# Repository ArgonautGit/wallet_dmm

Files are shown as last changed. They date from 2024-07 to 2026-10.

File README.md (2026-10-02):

# wallet_dmm

A multimeter the size of a credit card: DC volts, resistance, continuity and
diode test, shown on a 0.91" OLED, with three buttons, an RGB LED and a piezo
beeper. It runs from a small LiPo that charges over USB-C and is built around
an STM32L051K8, with Rust firmware and a simulation of the whole thing.

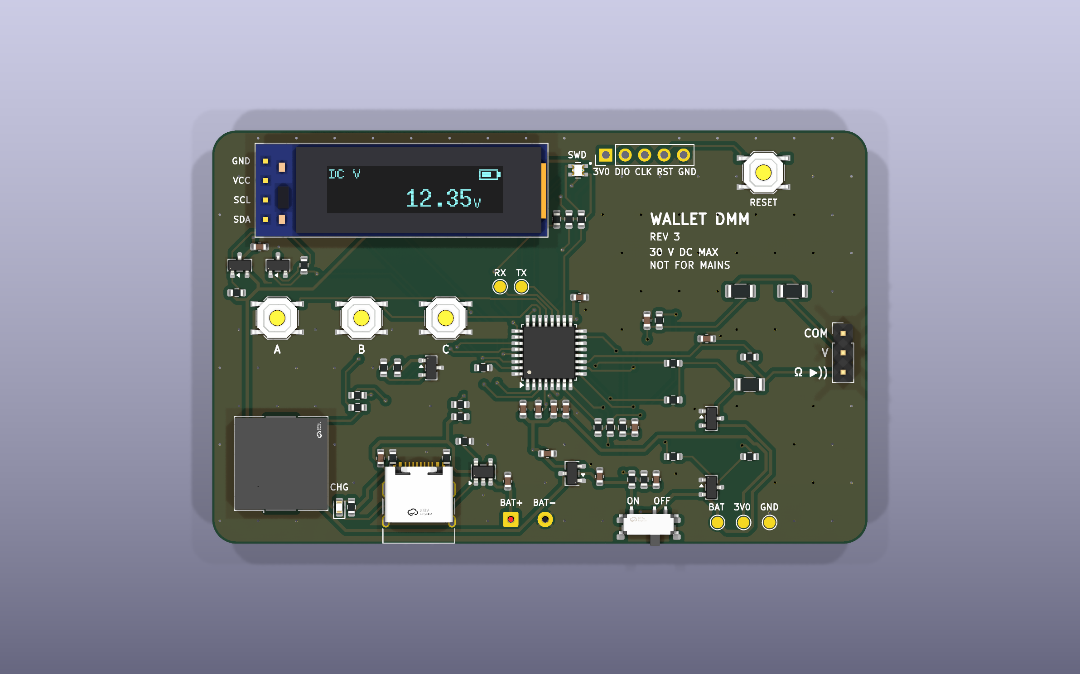
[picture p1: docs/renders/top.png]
The assembled board


This is revision 3. Rev 1 (the October 2024 JLCPCB order) is commit `a01ea68`;
rev 2 is the `v2` branch.

| | |
|---|---|
| Inputs | COM, V (10 MΩ) and Ω (resistance, continuity, diode) on a 2.54 mm header |
| Voltage | −30 V to +31 V; negative readings through a 1.55 V mid-rail bias |
| Resistance | 0–200 kΩ against a 0.1 % 10 kΩ reference, 150 kΩ–10 MΩ against 1 MΩ, autoranging |
| Continuity, diode | 0.3 mA test current, open-circuit 3.0 V |
| Overload | both inputs survive ±30 V DC; not for mains or anything above 30 V |
| Power | 3.7 V LiPo (protected cell), 100 mA USB-C charging, 3.0 V rail, about 5 µA off |
| Board | 85.6 × 54 mm (ID-1 card), 2 layers, 0.8 mm FR4 |

## Changes from rev 1 and rev 2

- **Power.** The CR1025 (rated 0.1 mA continuous) could not run an OLED. It is
  replaced by a LiPo charged from USB-C (MCP73831), a 1 µA 3.0 V LDO that
  stays on while the MCU sleeps in Stop mode, a slide switch that disconnects
  the battery, bulk decoupling, and a load switch (Q1/Q2) that cuts the OLED
  module's supply.
- **Piezo.** The always-running 555 and its two MOSFETs are gone. The MCU
  drives the piezo push-pull from TIM22 CH1/CH2 on PB4/PB5, which gives
  6 Vp-p from 3 V and draws nothing when silent.
- **Programming.** SWD is on PA13/PA14 with NRST, with nothing else on those
  pins. USART1 (PA9/PA10, also the ROM bootloader) is on test pads.
- **Measurement.** Separate V and Ω inputs. The V input is a 9.87 MΩ divider
  biased to a mid-rail reference, with a hold capacitor because the ADC wants
  a source below 50 kΩ. The Ω input has two reference ranges; its drive nodes
  are clamped to ground and the battery, so a voltage on it pushes at most
  2.5 mA into the cell instead of into the MCU or the 3.0 V rail. What the
  MCU pins' own clamps still pass would lift the rail while the MCU sleeps
  (the LDO cannot sink current), so a TL431 (U4) holds it below 3.32 V.
- **Everything else.** A resistor for each LED colour, with the anode on the
  battery so green and blue have headroom. The MCU's calibrated internal
  sensor replaces the TO-92 MCP9700. Decoupling sits at the pins. Every part
  is stocked by JLCPCB and carries its LCSC number. All libraries are in the
  repo.

## Layout of the repository

- `hardware/`: KiCad 10 project (schematic, board, project rules, footprints
  for the RGB LED and the OLED module, 3D models for every part)
- `scripts/`: generators for the schematic, board and 3D models, the
  autorouter wrapper, the fab-file export and the renders
- `fab/`: Gerbers, drill files, BOM and pick-and-place for JLCPCB, schematic
  and assembly PDFs
- `firmware/`: Rust firmware and its simulation (see
  [firmware/README.md](firmware/README.md))
- `docs/`: renders of the board and the simulation results

## Building

Everything runs in the dev shell (`nix develop`, or direnv).

```sh
./scripts/build.sh          # schematic -> ERC -> board -> DRC -> fab/
```

The schematic and board are generated by `scripts/gen_schematic.py` and
`scripts/gen_pcb.py`; edit those rather than the KiCad files, or the next
build will overwrite the change. Tracks come from `hardware/routes.json`.
After moving parts or changing the netlist, route again with Freerouting:

```sh
kicad-cli sch export netlist --format kicadsexpr -o build/wallet_dmm.net hardware/wallet_dmm.kicad_sch
python3 scripts/autoroute.py build/wallet_dmm.net
```

The build stops on any ERC or DRC error and checks that the board matches the
schematic.

The renders in `docs/renders/` and a GLB of the populated board
(`build/wallet_dmm.glb`, for any glTF viewer) come from:

```sh
./scripts/render.sh
```

Most parts use KiCad's own 3D models; the switches, buzzer, USB-C socket and
RGB LED use the manufacturers' models (via EasyEDA). The OLED module and the
battery are drawn by `scripts/gen_models.py`, which lights the OLED's pixels
with the firmware's volts screen:

```sh
nix develop .#models -c uv run --with cadquery python scripts/gen_models.py
```

## Ordering from JLCPCB

Upload `fab/wallet_dmm-gerbers.zip`: 2 layers, **0.8 mm**, 1 oz, any colour,
HASL lead-free or ENIG. For assembly, choose top side and upload
`fab/bom-jlcpcb.csv` and `fab/cpl-jlcpcb.csv`. In the placement preview,
check the orientation of U1 (pin 1 dot), U2, U3, Q1, Q2, D2, D3, D1 (cathode)
and D4 (anode corner, the dot in the silkscreen) before confirming.

Solder these by hand afterwards:

- J3: a 0.91" 128×32 SSD1306 I2C module, flat on the board, header pins cut
  short. Match the module's pin labels to the silkscreen (GND VCC SCL SDA).
- J2: a 3-pin header or the probe leads (COM, V, Ω).
- J5: the battery wires from the back, BAT+ to the square pad.
- J4 stays empty; hold a header in it for an ST-Link, or solder one while
  developing.

## Battery

A LiPo pouch cell with its own protection circuit, up to 30 × 40 × 4 mm,
taped to the marked area on the back (no pins poke through there). Charging
runs at 100 mA, so use 150 mAh or more; R3 sets the current (1000 V / R3).

## Bring-up

1. Before connecting anything, check that BAT and 3V0 (TP3, TP4) are not
   shorted to GND.
2. Connect the battery and slide SW5 to ON. TP4 reads 2.94–3.06 V. If it
   reads 0 V, the switch is the other way round from the silkscreen: fix the
   labels in `scripts/gen_pcb.py`.
3. Plug in USB-C: the CHG LED lights while the cell charges and goes out when
   it is full.
4. Flash over SWD (ST-Link on J4: 3V0, SWDIO, SWCLK, NRST, GND). Holding
   RESET while connecting works if firmware has put the MCU to sleep.
5. With the firmware running ([firmware/README.md](firmware/README.md)):
   short V to COM in DC V and hold C for 3 s to store the zero; do the same
   with the Ω leads in Ω mode. Then put 5–30 V on the V input, measure it with another
   meter, and send `cal <volts>` over the UART (TP2) to set the gain.

## Firmware

The firmware is in [firmware/](firmware/): Rust and Embassy, with all the
maths and the UI in a host-tested crate. Its README covers the buttons,
calibration, flashing and the simulation. The pins:

| Pin | Use |
|---|---|
| PA0 ADC_IN0 | E_LO: the low-range drive node, through R18 |
| PA1 ADC_IN1 | VMID, the bias under the V divider |
| PA2 | VMID_EN: high while measuring volts |
| PA3 | OHM_HI: high-range drive (1 MΩ), analog otherwise |
| PA4 ADC_IN4 | V input divider |
| PA5 ADC_IN5 | Ω input, through R21 into C13 |
| PA6 | OHM_LO: low-range drive (10 kΩ), analog otherwise |
| PA7 | VBUS present (high on USB) |
| PB1 ADC_IN9 | switched battery ÷ 2 |
| PA8, PA15, PB3 | LED blue, red, green (low = on; PA15/PB3 are TIM2 CH1/CH2) |
| PB4, PB5 | piezo, TIM22 CH1/CH2 in antiphase, about 4 kHz |
| PB6, PB7 | I2C1 to the OLED (address 0x3C) |
| PC15 | OLED power: high = on |
| PA11, PA12, PC14 | buttons A, B, C to GND (enable pull-ups) |
| PA9, PA10 | USART1 TX/RX on TP1/TP2 |

## Simulation

`firmware/simulate.sh` runs the front end in ngspice, feeds it through a
model of the ADC into the firmware's own maths, and runs the release binary
in Renode on an emulated STM32L051. Across 200 simulated boards with 1 %
parts, calibrated volts are within ±4 mV up to ±5 V and ±33 mV at ±30 V,
and ohms within ±0.34 % from 1 kΩ to 100 kΩ. The details and plots are in
[firmware/README.md](firmware/README.md#simulation) and
[docs/simulation/](docs/simulation/).

The firmware's display in Renode, step by step

## Renders

| Front | Back, with the battery |
|---|---|
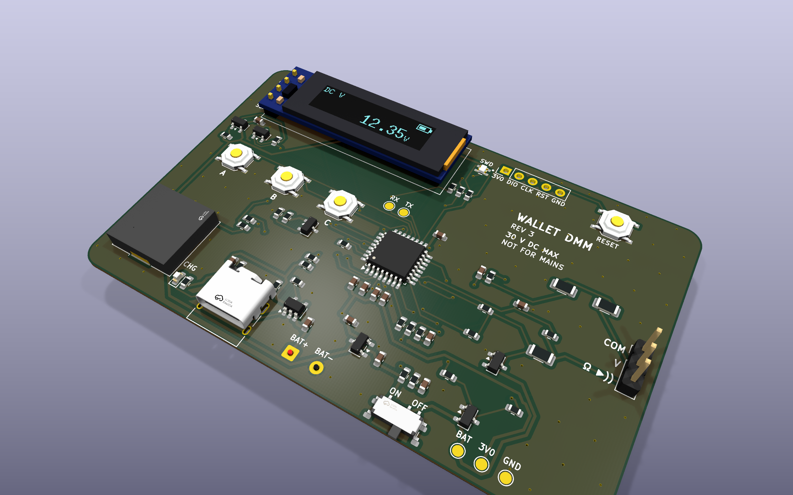
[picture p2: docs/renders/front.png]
Front
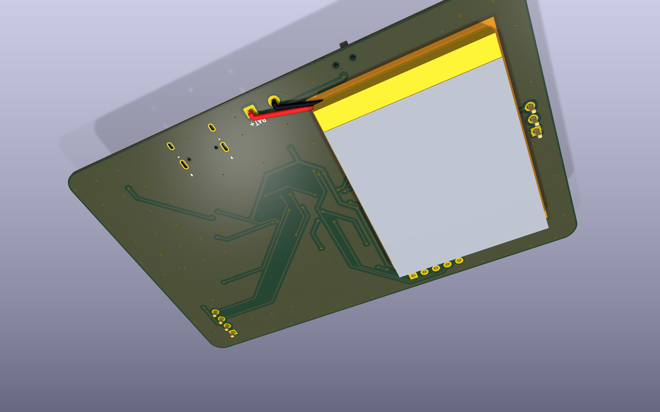
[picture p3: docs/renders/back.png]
Back
|  |  |

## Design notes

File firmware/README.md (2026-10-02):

# Firmware

Rust and Embassy on the STM32L051K8, with a simulation of the analog front
end, the ADC and the firmware itself.

- `core/`: everything that is not a pin. The measurement maths (divider,
  references, VDDA from VREFINT, battery, temperature), the UI state machine
  and the 128×32 screen layout. `no_std`, tested on the host.
- `app/`: the firmware binary. Pins, ADC registers, EEPROM, Stop mode.
- `sim/`: the front end in ngspice, an ADC model that feeds `core`, and plots.
- `renode/`: the release ELF running on an emulated STM32L051 with a model
  of the front end behind its ADC.

## Using the meter

| Button | Short press | Long press |
|---|---|---|
| A | next mode: DC V, Ω, continuity, diode, info | 1.5 s: off |
| B | hold the display (again to release) | |
| C | relative: show readings against the current one | 3 s, probes shorted: store the zero |

Any button wakes the meter from off. It turns itself off after 5 minutes
without a press, or when the battery falls below 3.35 V, unless USB is
connected; the blue LED blinks while it is.

- **DC V**, on the V input: −30 V to +31 V, "OL" beyond. Readings are
  averaged while the input holds still and start over when it moves.
- **Ω**, on the Ω input: the 10 kΩ range up to 200 kΩ, the 1 MΩ range above
  (back below 150 kΩ), "OL" when open. Before each reading the drive is
  pulled low to look for a source on the input; "VOLTS!" and the red LED
  mean there is one, and nothing is driven until it goes.
- **Continuity**: beeps, with the green LED, below 50 Ω. Reads every 30 ms.
- **Diode**: forward voltage at up to 0.3 mA, "OL" when open or reversed.
- **Info**: battery voltage and charge, USB, the MCU's temperature, VDDA.

## Calibration

Stored in the data EEPROM, so it survives power-off and reflashing.

- **Zero** (volts offset, lead resistance): short the probes in DC V, Ω or
  continuity and hold C for 3 s.
- **Gain**: put a steady 5–30 V on the V input, measure it with a meter you
  trust, and send `cal <volts>` (for example `cal 10.047`) to USART1 RX on
  TP2. The firmware replies with the new gain, or with why it refused (not
  in DC V, below 1 V, or more than 5 % off).

## Log

USART1 TX on TP1, 115200 8N1. One line per reading, with µV, mΩ, the rail
(µV), the battery (µV) and the temperature (0.1 °C):

```
DC V 12335998 vdda 2968467 bat 3899510 temp 241
OHMS 470046813 vdda 2968467 bat 3899782 temp 241
button A long
off
```

## Building and flashing

In the firmware dev shell (`nix develop .#firmware` at the repository root):

```sh
cargo test -p dmm-core     # host tests, in firmware/
cd app
cargo build --release      # 35 KB of the 64 KB flash
cargo run --release        # flash over SWD (ST-Link on J4) with probe-rs
```

The app builds for `thumbv6m-none-eabi` through `app/.cargo/config.toml`,
so run cargo from `app/`. If the meter is off (Stop mode), probe-rs cannot
attach: hold RESET while it connects, or add `--connect-under-reset` to the
runner in that file.

## Simulation

```sh
./simulate.sh    # in firmware/; refreshes docs/simulation/
```

It runs four layers:

1. `cargo test`: the maths and UI.
2. `sim/spice.py`: the front end in ngspice. DC sweeps of both inputs,
   30 V on each input with the MCU running and asleep, the continuity and V
   settling transients, and 200 boards with 1 % resistors (0.1 % for R17).
3. `dmm-sim`: turns those node voltages into ADC codes with offset, gain
   error, INL, noise, 16× oversampling and each board's own ADC errors, then
   into readings through `core`, exactly as the firmware does. It also draws
   each screen with the firmware's renderer.
4. `renode/run.py`: the release ELF on an emulated STM32L051. A Python
   peripheral stands in for the ADC and solves the front end from the GPIO
   state the firmware sets up. A scripted session presses buttons, changes
   what the probes touch, and types a calibration command. The SSD1306's I2C
   traffic is decoded back into frames.

Results, in [docs/simulation](../docs/simulation/):

| Check | Result |
|---|---|
| Volts, uncalibrated | ±61 mV up to ±5 V, ±505 mV at ±30 V |
| Volts, zero and gain calibrated | ±4 mV up to ±5 V, ±33 mV at ±30 V |
| Ohms, leads zeroed, up to 100 Ω | ±3.1 Ω |
| Ohms, 1 kΩ–100 kΩ | ±0.34 % |
| Ohms, 1 MΩ / 10 MΩ | ±1.5 % / ±3.6 % |
| Diode test, 1N4148 / red LED | 0.516 V / 1.704 V (true 0.516 / 1.705) |
| 30 V on the Ω input | 2.5 mA into the battery, 65 mW in R17 |
| Same, MCU asleep | rail held at 3.32 V by U4 (29.5 V without it) |
| Continuity | beeps at the first reading after contact, 15 ms |
| V input settling | 161 ms to 5 mV; readings every 200 ms |

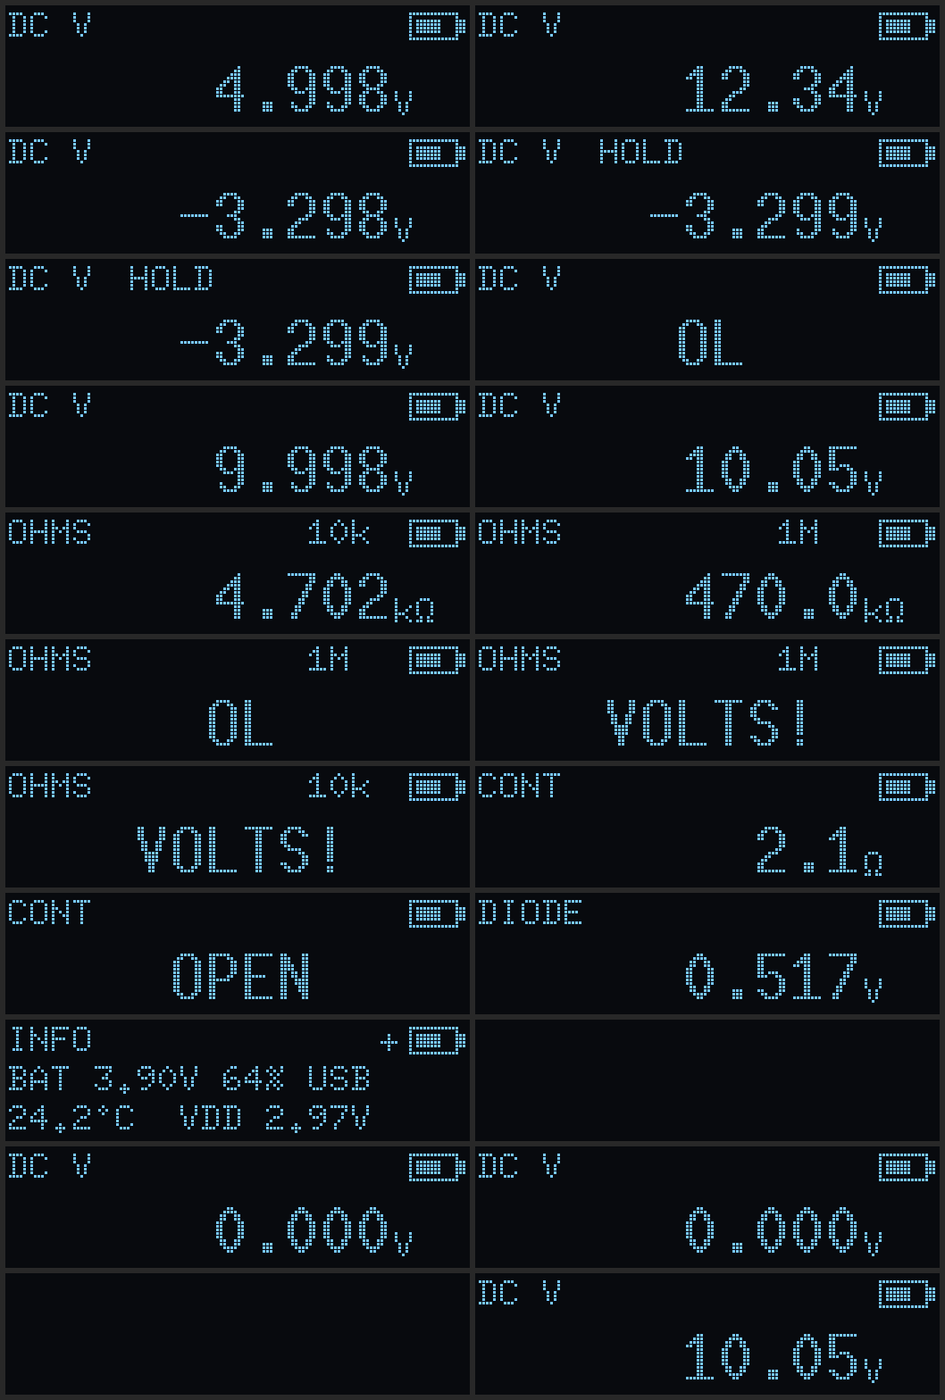
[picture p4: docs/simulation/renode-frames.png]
Readings from the firmware running in Renode


The Renode session (`session.md` there) checks the log line, LEDs, piezo and
OLED power at the end of each step, including hold, overload on both inputs,
autoranging, power-off and wake, and the zero and gain surviving a reset.

Renode 1.16 differs from the real chip in ways that `run.py` works around:
a system reset clears flash and pulls every GPIO input low (the reset macro
reloads the ELF and lets the buttons go), EXTI_IMR resets to 0 instead of
0x3F840000 (which would mask USART1's interrupt), and PC14 does not reach
the EXTI (button C drives the EXTI line directly).

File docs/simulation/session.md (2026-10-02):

| Step | Last UART line | LEDs lit | Piezo | OLED power |
|---|---|---|---|---|
| volts_5V | DC V 5001079 vdda 2968248 bat 3899948 temp 242 | - | off | on |
| volts_12V34 | DC V 12335998 vdda 2968467 bat 3899510 temp 241 | - | off | on |
| volts_neg3V3 | DC V -3296296 vdda 2968577 bat 3899564 temp 241 | - | off | on |
| volts_hold | DC V -3302042 vdda 2967918 bat 3899242 temp 242 | - | off | on |
| volts_hold_kept | DC V 19992218 vdda 2967918 bat 3899422 temp 243 | - | off | on |
| volts_overload | DC V overload vdda 2968357 bat 3899728 temp 242 | - | off | on |
| volts_10V | DC V 9998416 vdda 2968357 bat 3899638 temp 242 | - | off | on |
| volts_cal_10V05 | DC V 10048082 vdda 2967698 bat 3898952 temp 241 | - | off | on |
| ohms_4k7 | OHMS 4702061 vdda 2968138 bat 3899350 temp 242 | - | off | on |
| ohms_470k | OHMS 470046813 vdda 2968467 bat 3899782 temp 241 | - | off | on |
| ohms_open | OHMS open vdda 2968138 bat 3899168 temp 242 | - | off | on |
| ohms_voltage | OHMS overload vdda 2968357 bat 3899456 temp 242 | red | off | on |
| ohms_negative_voltage | OHMS overload vdda 2968357 bat 3899274 temp 243 | red | off | on |
| continuity_short | CONT 2357 vdda 2968138 bat 3899258 temp 243 | green | on | on |
| continuity_open | CONT open vdda 2968138 bat 3899622 temp 242 | - | off | on |
| diode_1n4148 | DIODE 517094 vdda 2968028 bat 3899568 temp 242 | - | off | on |
| info_usb | INFO - vdda 2968248 bat 3899404 temp 242 | blue | off | on |
| power_off | off | - | off | off |
| wake_volts_0V | DC V 1467 vdda 2968248 bat 3899948 temp 242 | - | off | on |
| zero_stored | DC V 345 vdda 2967808 bat 3898734 temp 243 | - | off | on |
| power_off_again | off | - | off | off |
| wake_calibration_kept | DC V 10048761 vdda 2968467 bat 3899510 temp 241 | - | off | on |

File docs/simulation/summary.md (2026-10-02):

| Check | Result |
|---|---|
| Volts, 200 boards, uncalibrated | ±61 mV up to ±5 V, ±505 mV at ±30 V |
| Volts, 200 boards, calibrated at 0 V and 10 V | ±4 mV up to ±5 V, ±33 mV at ±30 V |
| Ohms, 200 boards, leads zeroed, up to 100 Ω | ±3.1 Ω |
| Ohms, 200 boards, leads zeroed, 1 kΩ–100 kΩ | ±0.34 % |
| Ohms, 200 boards, leads zeroed, 1 MΩ | ±1.47 % |
| Ohms, 200 boards, leads zeroed, 10 MΩ | ±3.64 % |
| Diode test, 1N4148 | reads 0.516 V (true 0.516 V) |
| Diode test, red LED | reads 1.704 V (true 1.705 V) |
| 30 V on the Ω input | 2.5 mA into the battery, 65 mW in R17 |
| Same, MCU asleep | rail 29.5 V without U4, 3.32 V with it |
| Continuity response | beeps at the first reading after contact (15 ms) |
| V input settling | 161 ms to 5 mV (firmware reads every 200 ms) |

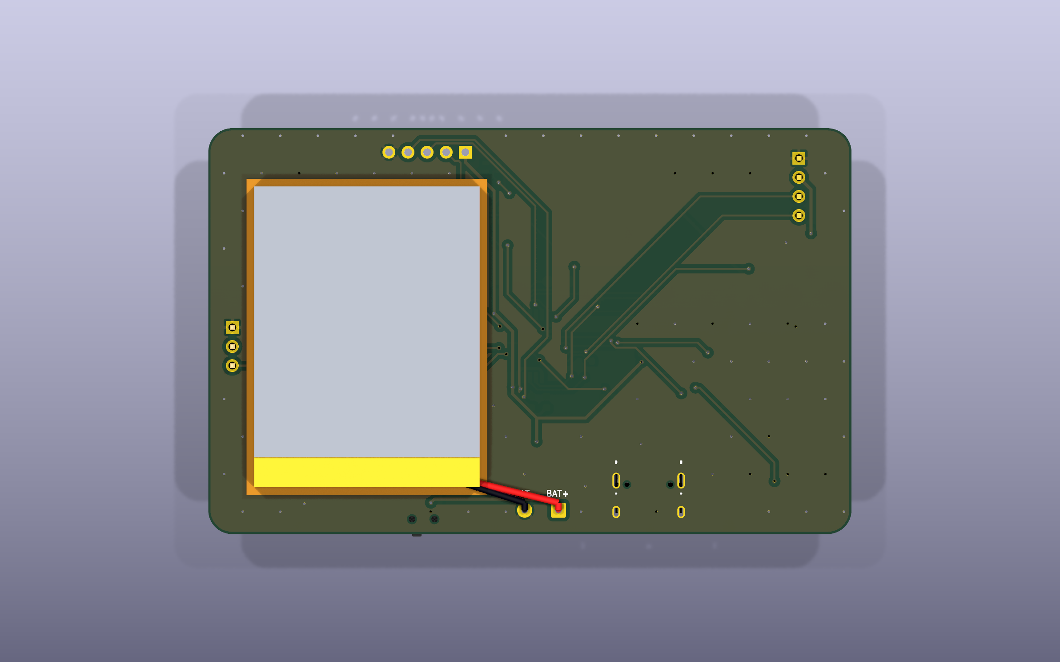
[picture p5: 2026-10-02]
docs/renders/bottom.png

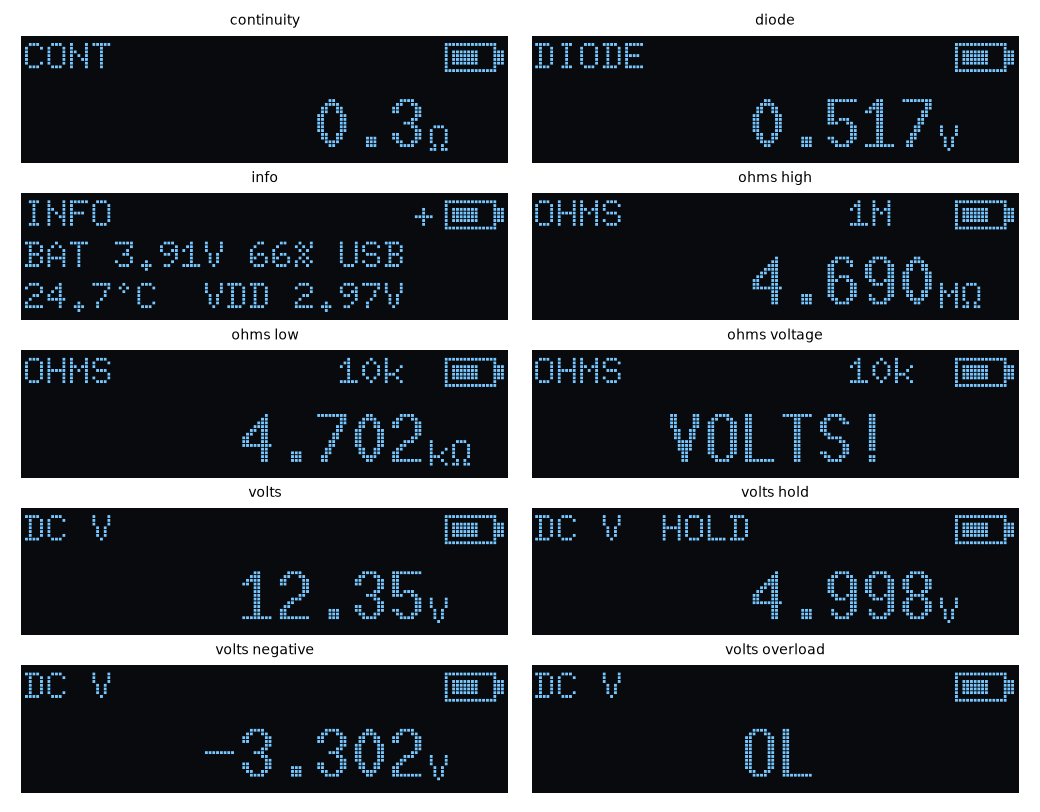
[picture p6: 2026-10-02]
docs/simulation/screens.png

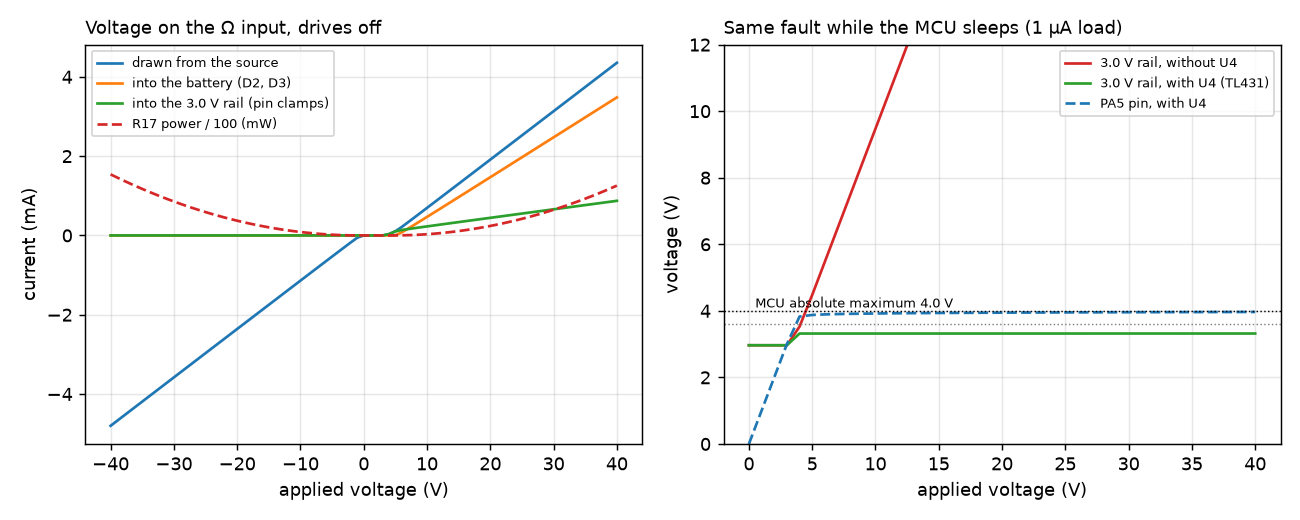
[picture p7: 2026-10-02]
docs/simulation/overload.png

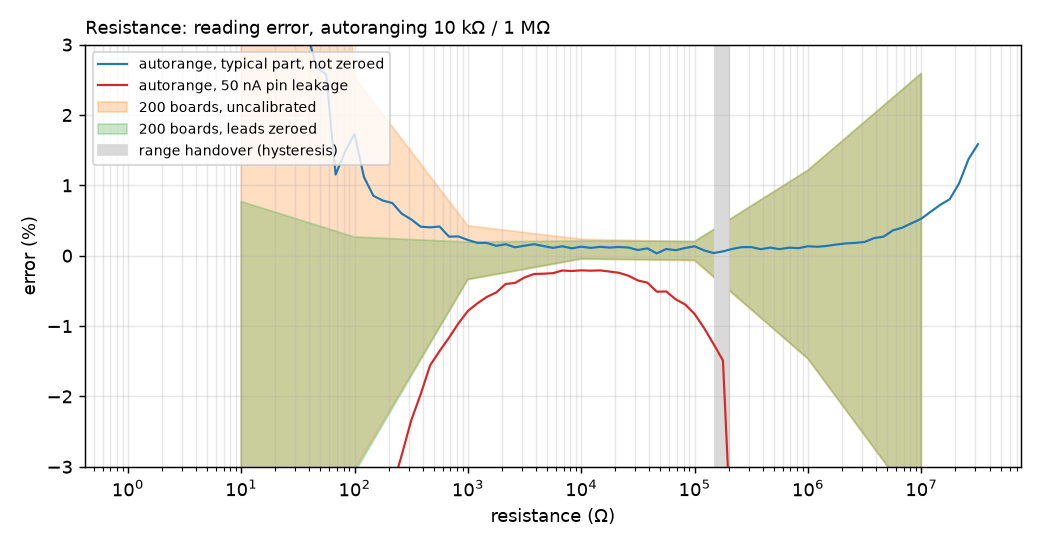
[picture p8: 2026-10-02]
docs/simulation/ohms.png

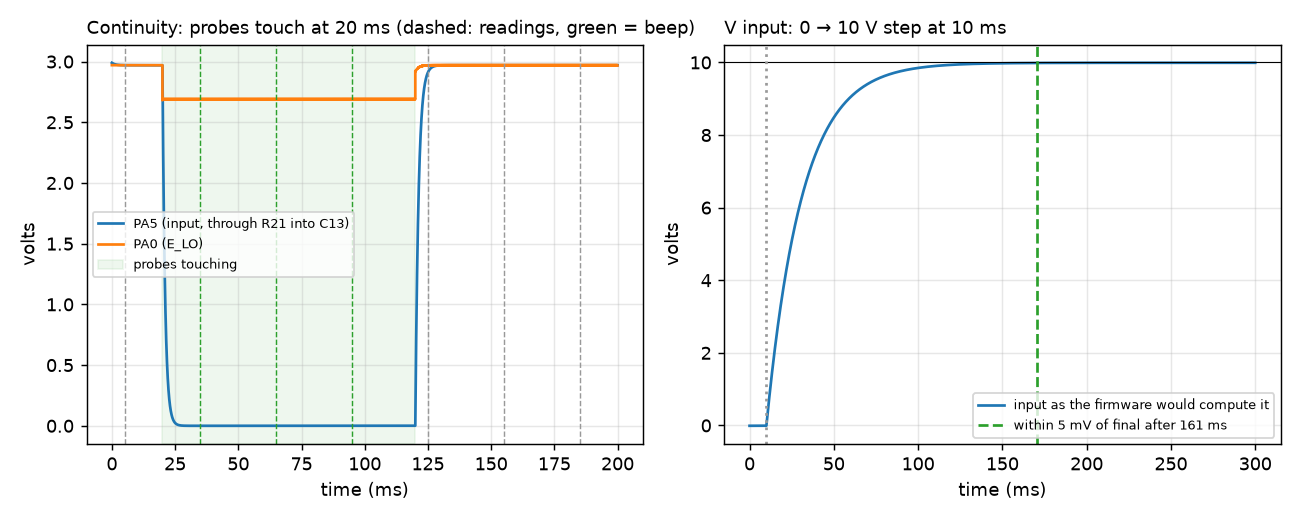
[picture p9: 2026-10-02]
docs/simulation/transients.png

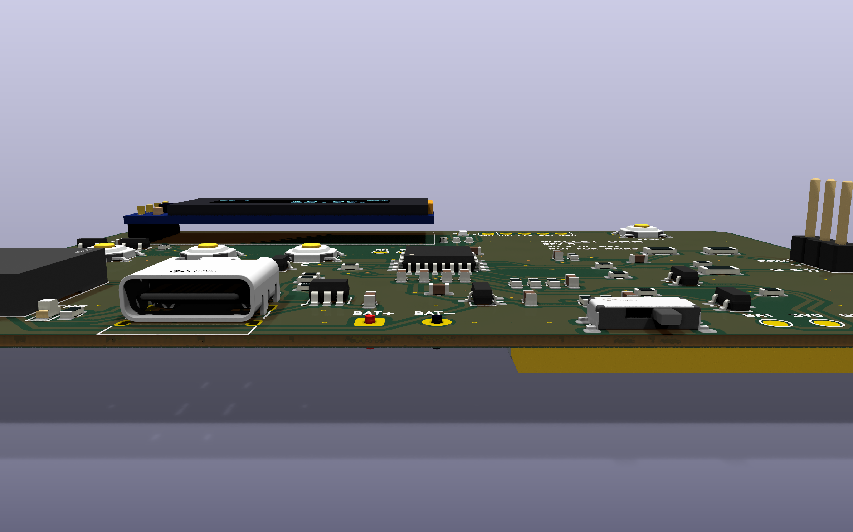
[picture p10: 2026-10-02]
docs/renders/edge.png

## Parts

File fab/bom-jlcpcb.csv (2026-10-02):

Comment | Designator | Footprint | LCSC Part #
PKLCS1212E4001 | BZ1 | Buzzer_Murata_PKLCS1212E | C113159
4.7uF | C1,C2 | C_0603_1608Metric | C19666
1uF | C3,C8,C12,C14 | C_0603_1608Metric | C15849
10uF | C4 | C_0603_1608Metric | C19702
100nF | C5,C6,C7,C10 | C_0603_1608Metric | C14663
10nF | C9 | C_0603_1608Metric | C57112
47nF | C11 | C_0603_1608Metric | C1622
22nF | C13 | C_0603_1608Metric | C21122
CHG red | D1 | LED_0603_1608Metric | C2286
BAV199 | D2,D3 | SOT-23 | C40919
RGB | D4 | LED_RGB_1615_CA | C601683
USB-C (charge only) | J1 | USB_C_Receptacle_HRO_TYPE-C-31-M-12 | C165948
AO3401A | Q1 | SOT-23 | C15127
2N7002 | Q2 | SOT-23 | C8545
5.1k | R1,R2,R14 | R_0603_1608Metric | C23186
10k | R3,R5,R9,R18 | R_0603_1608Metric | C25804
1k | R4,R15,R16,R19,R25 | R_0603_1608Metric | C21190
15k | R6 | R_0603_1608Metric | C22809
1M | R7,R8,R20,R30 | R_0603_1608Metric | C22935
4.7M | R10,R11 | R_1206_3216Metric | C37800
470k | R12 | R_0603_1608Metric | C23178
4.7k | R13 | R_0603_1608Metric | C23162
10k 0.1% | R17 | R_1206_3216Metric | C136889
47k | R21 | R_0603_1608Metric | C25819
100k | R22,R23 | R_0603_1608Metric | C25803
680 | R24 | R_0603_1608Metric | C23228
330 | R26 | R_0603_1608Metric | C23138
220 | R27,R28 | R_0603_1608Metric | C22962
330k | R29 | R_0603_1608Metric | C23137
BUTTON A | SW1 | SW_Push_1P1T_XKB_TS-1187A | C318884
BUTTON B | SW2 | SW_Push_1P1T_XKB_TS-1187A | C318884
BUTTON C | SW3 | SW_Push_1P1T_XKB_TS-1187A | C318884
RESET | SW4 | SW_Push_1P1T_XKB_TS-1187A | C318884
POWER | SW5 | SW_SPDT_Shouhan_MSK12C02 | C431540
STM32L051K8T6 | U1 | LQFP-32_7x7mm_P0.8mm | C915970
MCP73831T-2ACI/OT | U2 | SOT-23-5 | C424093
XC6206P302MR (3.0 V) | U3 | SOT-23-3 | C9972
TL431AIDBZR | U4 | SOT-23 | C23892

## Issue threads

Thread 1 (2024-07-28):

Extend autodiff workflow script to pcb

ArgonautGit, 2024-07-28:
Most of the required code is just commented out. The main issue is that `kicad-cli` needs more arguments for the pcb svg export, something like layers and such. May need to add functionality for variable numbers of layers.

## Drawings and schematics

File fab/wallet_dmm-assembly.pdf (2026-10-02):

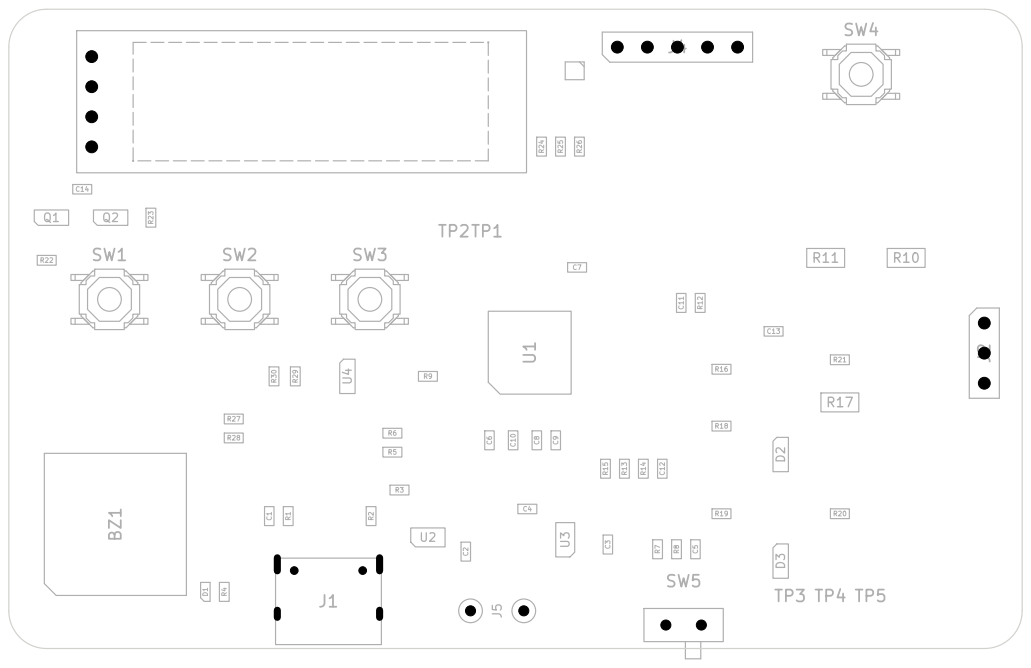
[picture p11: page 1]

Size: A4 | Rev: 3
KiCad E.D.A. 10.0.6 | Id: 1/1

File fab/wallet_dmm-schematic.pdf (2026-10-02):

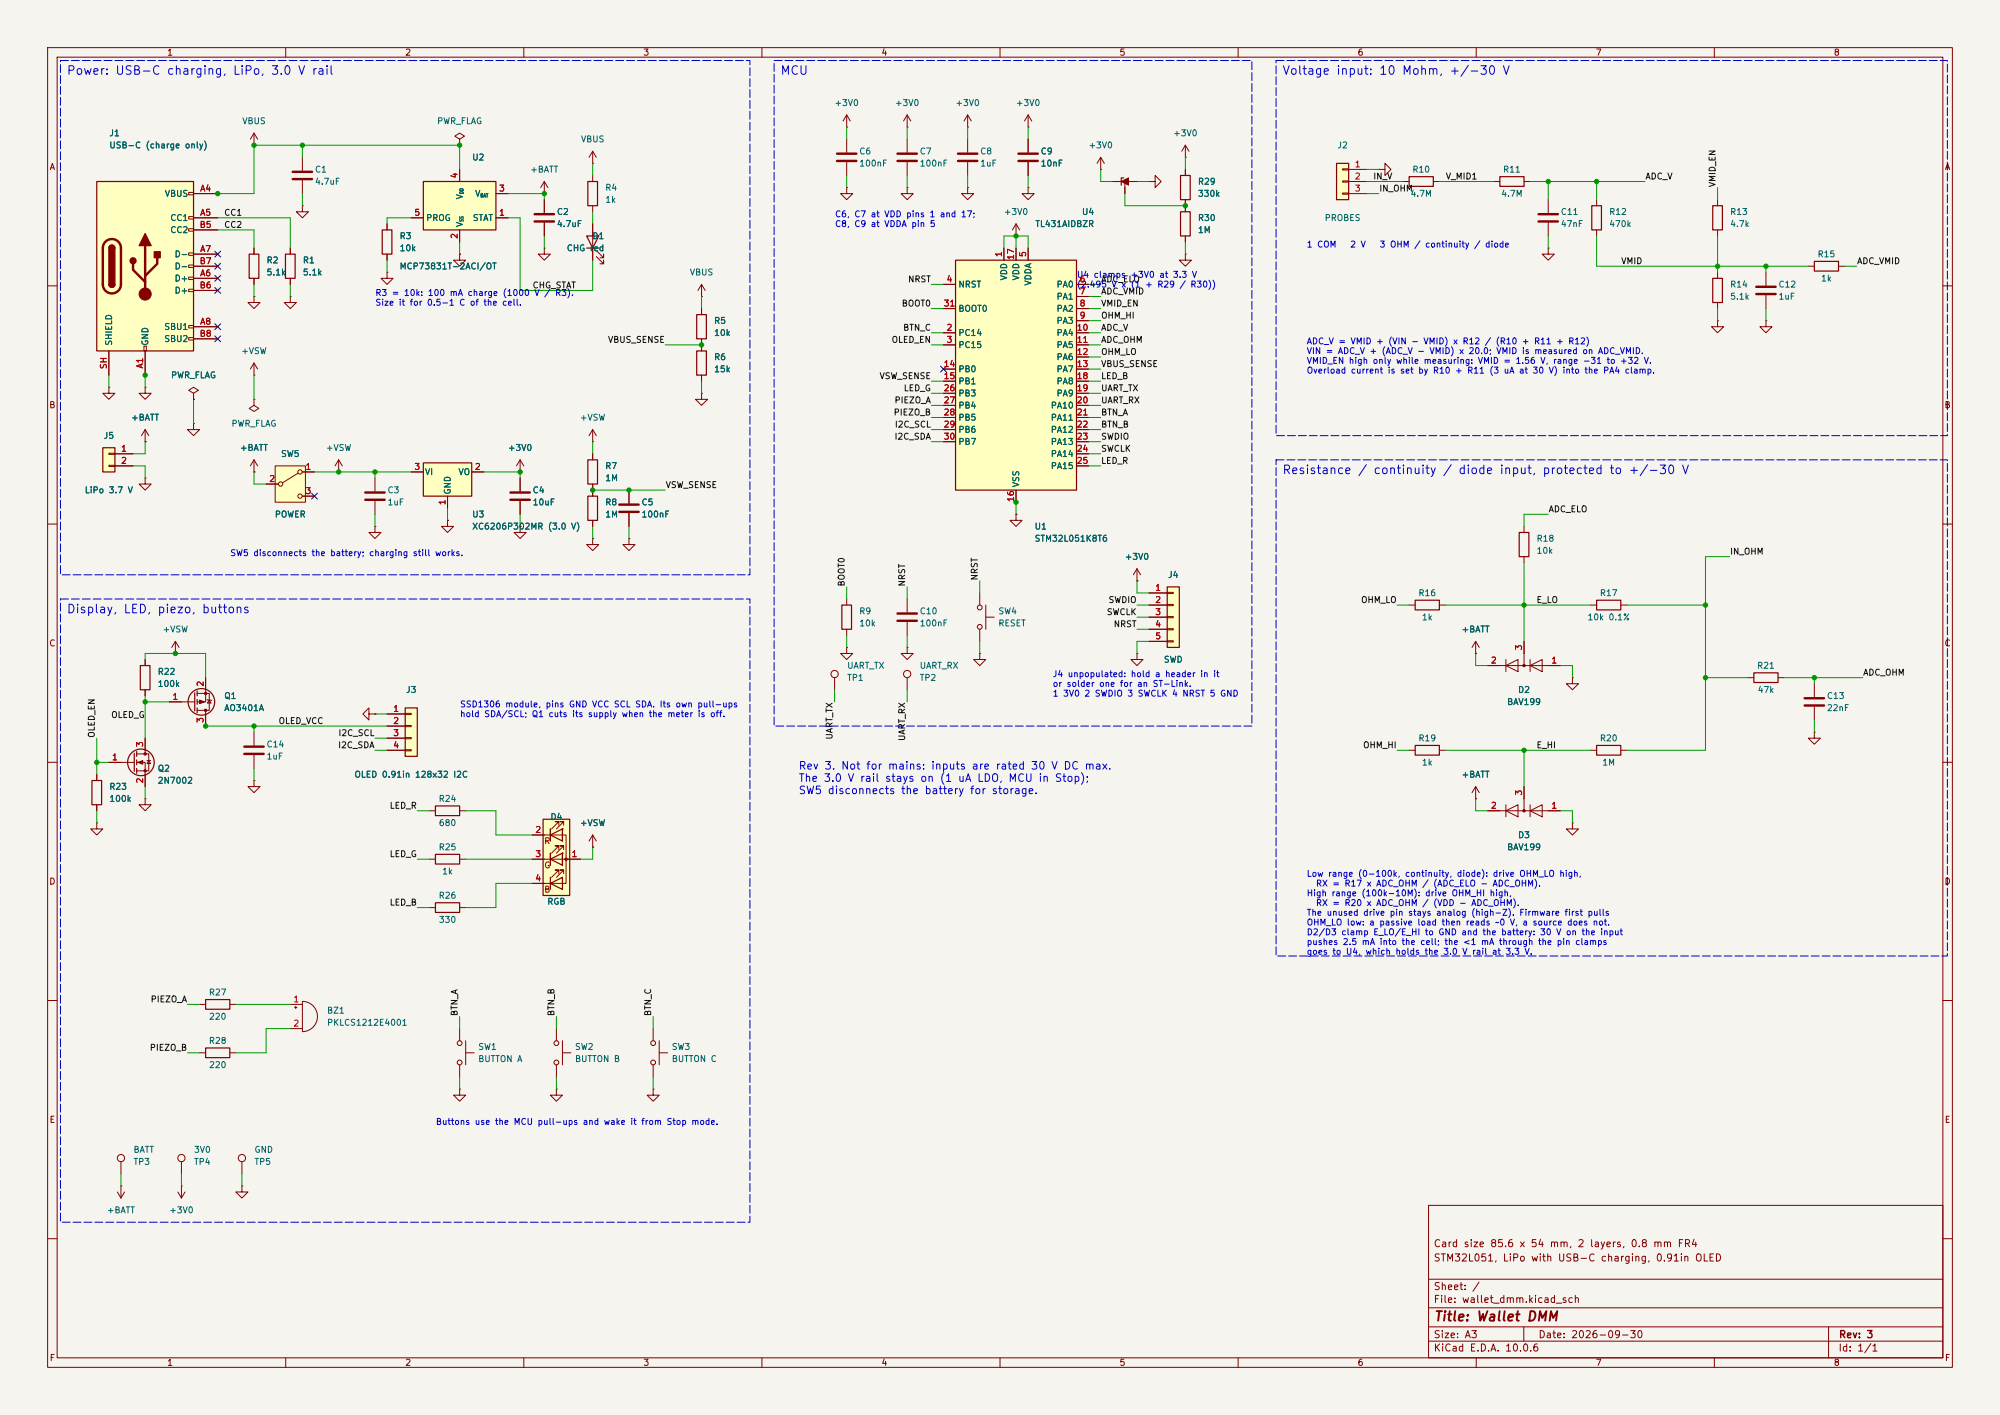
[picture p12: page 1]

C6, C7 at VDD pins 1 and 17;
C8, C9 at VDDA pin 5 Rev 3. Not for mains: inputs are rated 30 V DC max. The 3.0 V rail stays on (1 uA LDO, MCU in Stop);

1 PC14 2 PC15 3 NRST 4 VDDA 5 PA0 6 PA1 7 PA2 8 PA3 9 PA4 10 PA5 11 PA6 12 PA7 13 PB0 14 PB1 15 VSS 16 VDD 17 PA8 18 PA9 19 PA10 20 PA11 21 PA12 22 PA13 23 PA14 24 PA15 25 PB3 26 PB4 27 PB5 28 PB6 29 PB7 30 BOOT0 31 U1

1 PC14 2 PC15 3 NRST 4 VDDA 5 PA0 6 PA1 7 PA2 8 PA3 9 PA4 10 PA5 11 PA6 12 PA7 13 PB0 14 PB1 15 VSS 16 VDD 17 PA8 18 PA9 19 PA10 20 PA11 21 PA12 22 PA13 23 PA14 24 PA15 25 PB3 26 PB4 27 PB5 28 PB6 29 PB7 30 BOOT0 31 +3V0

R3 = 10k: 100 mA charge (1000 V / R3). Size it for 0.5-1 C of the cell. SW5 disconnects the battery; charging still works. Display, LED, piezo, buttons

(2.495 V x (1 + R29 / R30)) SSD1306 module, pins GND VCC SCL SDA. Its own pull-ups hold SDA/SCL; Q1 cuts its supply when the meter is off.

ADC_V = VMID + (VIN - VMID) x R12 / (R10 + R11 + R12) VIN = ADC_V + (ADC_V - VMID) x 20.0; VMID is measured on ADC_VMID. VMID_EN high only while measuring: VMID = 1.56 V, range -31 to +32 V. Overload current is set by R10 + R11 (3 uA at 30 V) into the PA4 clamp. J4 unpopulated: hold a header in it or solder one for an ST-Link. 1 3V0 2 SWDIO 3 SWCLK 4 NRST 5 GND

Resistance / continuity / diode input, protected to +/-30 V

High range (100k-10M): drive OHM_HI high, RX = R20 x ADC_OHM / (VDD - ADC_OHM). The unused drive pin stays analog (high-Z). Firmware first pulls OHM_LO low: a passive load then reads ~0 V, a source does not. D2/D3 clamp E_LO/E_HI to GND and the battery: 30 V on the input

pushes 2.5 mA into the cell; the <1 mA through the pin clamps goes to U4, which holds the 3.0 V rail at 3.3 V.

Buttons use the MCU pull-ups and wake it from Stop mode.

Card size 85.6 x 54 mm, 2 layers, 0.8 mm FR4
STM32L051, LiPo with USB-C charging, 0.91in OLED

Size: A3 | Rev: 3 | F Date: 2026-09-30
KiCad E.D.A. 10.0.6 | Id: 1/1

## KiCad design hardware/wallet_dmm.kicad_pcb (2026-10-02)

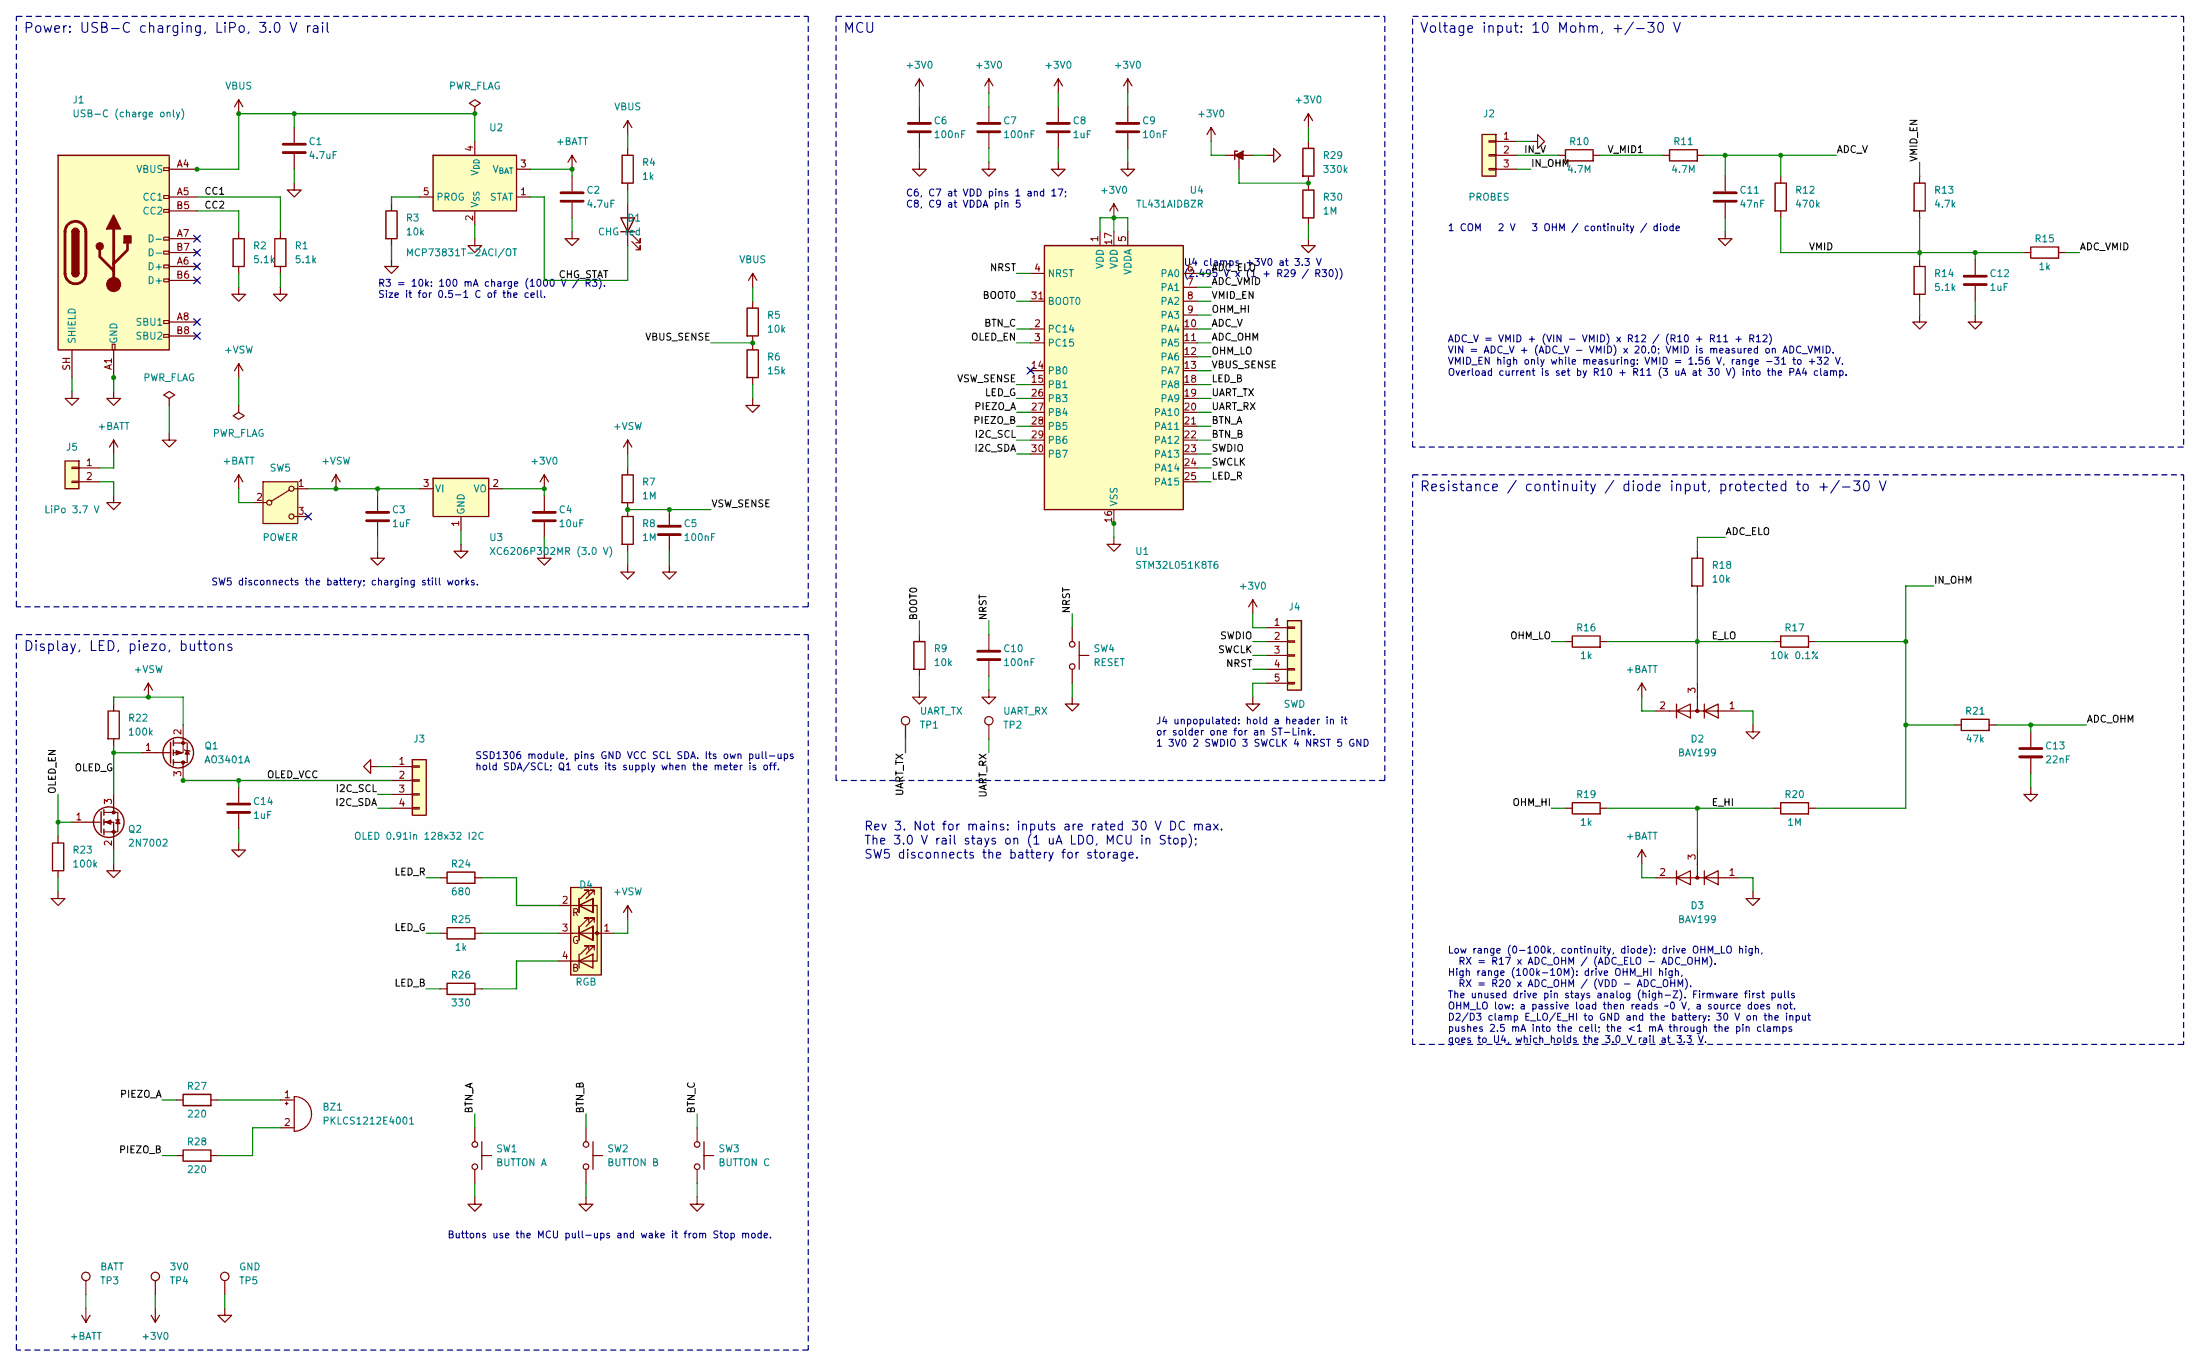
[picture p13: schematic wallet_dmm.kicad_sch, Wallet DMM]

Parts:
BZ1: PKLCS1212E4001; Buzzer_Murata_PKLCS1212E; MPN PKLCS1212E4001-R1; LCSC C113159
C1, C2: 4.7uF; C_0603_1608Metric; MPN CL10A475KO8NNNC; LCSC C19666
C3, C8, C12, C14: 1uF; C_0603_1608Metric; MPN CL10A105KB8NNNC; LCSC C15849
C4: 10uF; C_0603_1608Metric; MPN CL10A106KP8NNNC; LCSC C19702
C5, C6, C7, C10: 100nF; C_0603_1608Metric; MPN CC0603KRX7R9BB104; LCSC C14663
C9: 10nF; C_0603_1608Metric; MPN 0603B103K500NT; LCSC C57112
C11: 47nF; C_0603_1608Metric; MPN CL10B473KB8NNNC; LCSC C1622
C13: 22nF; C_0603_1608Metric; MPN CL10B223KB8NNNC; LCSC C21122
D1: CHG red; LED_0603_1608Metric; MPN KT-0603R; LCSC C2286
D2, D3: BAV199; SOT-23; MPN BAV199,215; LCSC C40919
D4: RGB; LED_RGB_1615_CA; MPN TJ-S1615CY6TGLCCYRGB-A5; LCSC C601683
J1: USB-C (charge only); USB_C_Receptacle_HRO_TYPE-C-31-M-12; MPN TYPE-C-31-M-12; LCSC C165948
J2: PROBES; PinHeader_1x03_P2.54mm_Vertical
J3: OLED 0.91in 128x32 I2C; OLED_0.91in_128x32_Module
J4: SWD; PinHeader_1x05_P2.54mm_Vertical
J5: LiPo 3.7 V; SolderWire-0.25sqmm_1x02_P4.5mm_D0.65mm_OD2mm
Q1: AO3401A; SOT-23; MPN AO3401A; LCSC C15127
Q2: 2N7002; SOT-23; MPN 2N7002; LCSC C8545
R1, R2, R14: 5.1k; R_0603_1608Metric; MPN 0603WAF5101T5E; LCSC C23186
R3, R5, R9, R18: 10k; R_0603_1608Metric; MPN 0603WAF1002T5E; LCSC C25804
R4, R15, R16, R19, R25: 1k; R_0603_1608Metric; MPN 0603WAF1001T5E; LCSC C21190
R6: 15k; R_0603_1608Metric; MPN 0603WAF1502T5E; LCSC C22809
R7, R8, R20, R30: 1M; R_0603_1608Metric; MPN 0603WAF1004T5E; LCSC C22935
R10, R11: 4.7M; R_1206_3216Metric; MPN 1206W4F4704T5E; LCSC C37800
R12: 470k; R_0603_1608Metric; MPN 0603WAF4703T5E; LCSC C23178
R13: 4.7k; R_0603_1608Metric; MPN 0603WAF4701T5E; LCSC C23162
R17: 10k 0.1%; R_1206_3216Metric; MPN RT1206BRD0710KL; LCSC C136889
R21: 47k; R_0603_1608Metric; MPN 0603WAF4702T5E; LCSC C25819
R22, R23: 100k; R_0603_1608Metric; MPN 0603WAF1003T5E; LCSC C25803
R24: 680; R_0603_1608Metric; MPN 0603WAF6800T5E; LCSC C23228
R26: 330; R_0603_1608Metric; MPN 0603WAF3300T5E; LCSC C23138
R27, R28: 220; R_0603_1608Metric; MPN 0603WAF2200T5E; LCSC C22962
R29: 330k; R_0603_1608Metric; MPN 0603WAF3303T5E; LCSC C23137
SW1: BUTTON A; SW_Push_1P1T_XKB_TS-1187A; MPN TS-1187A-B-A-B; LCSC C318884
SW2: BUTTON B; SW_Push_1P1T_XKB_TS-1187A; MPN TS-1187A-B-A-B; LCSC C318884
SW3: BUTTON C; SW_Push_1P1T_XKB_TS-1187A; MPN TS-1187A-B-A-B; LCSC C318884
SW4: RESET; SW_Push_1P1T_XKB_TS-1187A; MPN TS-1187A-B-A-B; LCSC C318884
SW5: POWER; SW_SPDT_Shouhan_MSK12C02; MPN MSK12C02; LCSC C431540
TP1: UART_TX; TestPoint_Pad_D1.5mm
TP2: UART_RX; TestPoint_Pad_D1.5mm
TP3: BATT; TestPoint_Pad_D1.5mm
TP4: 3V0; TestPoint_Pad_D1.5mm
TP5: GND; TestPoint_Pad_D1.5mm
U1: STM32L051K8T6; LQFP-32_7x7mm_P0.8mm; MPN STM32L051K8T6; LCSC C915970
U2: MCP73831T-2ACI/OT; SOT-23-5; MPN MCP73831T-2ACI/OT; LCSC C424093
U3: XC6206P302MR (3.0 V); SOT-23-3; MPN XC6206P302MR-G; LCSC C9972
U4: TL431AIDBZR; SOT-23; MPN TL431AIDBZR; LCSC C23892

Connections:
+3V0: C4.1, C6.1, C7.1, C8.1, C9.1, J4.1, R29.1, TP4.1, U1.1 (VDD), U1.5 (VDDA), U1.17 (VDD), U3.2 (VO), U4.1 (K)
+BATT: C2.1, D2.2 (A), D3.2 (A), J5.1, SW5.2 (B), TP3.1, U2.3 (V_{BAT})
+VSW: C3.1, D4.1 (A), Q1.2 (S), R7.1, R22.1, SW5.1 (A), U3.3 (VI)
/ADC_ELO: R18.1, U1.6 (PA0)
/ADC_OHM: C13.1, R21.2, U1.11 (PA5)
/ADC_V: C11.1, R11.2, R12.1, U1.10 (PA4)
/ADC_VMID: R15.2, U1.7 (PA1)
/BOOT0: R9.1, U1.31 (BOOT0)
/BTN_A: SW1.1, U1.21 (PA11)
/BTN_B: SW2.1, U1.22 (PA12)
/BTN_C: SW3.1, U1.2 (PC14)
/CC1: J1.A5 (CC1), R1.1
/CC2: J1.B5 (CC2), R2.1
/CHG_STAT: D1.1 (K), U2.1 (STAT)
/E_HI: D3.3 (K), R19.2, R20.1
/E_LO: D2.3 (K), R16.2, R17.1, R18.2
/I2C_SCL: J3.3, U1.29 (PB6)
/I2C_SDA: J3.4, U1.30 (PB7)
/IN_OHM: J2.3, R17.2, R20.2, R21.1
/IN_V: J2.2, R10.1
/LED_B: R26.1, U1.18 (PA8)
/LED_G: R25.1, U1.26 (PB3)
/LED_R: R24.1, U1.25 (PA15)
/NRST: C10.1, J4.4, SW4.1, U1.4 (NRST)
/OHM_HI: R19.1, U1.9 (PA3)
/OHM_LO: R16.1, U1.12 (PA6)
/OLED_EN: Q2.1 (G), R23.1, U1.3 (PC15)
/OLED_G: Q1.1 (G), Q2.3 (D), R22.2
/OLED_VCC: C14.1, J3.2, Q1.3 (D)
/PIEZO_A: R27.1, U1.27 (PB4)
/PIEZO_B: R28.1, U1.28 (PB5)
/SWCLK: J4.3, U1.24 (PA14)
/SWDIO: J4.2, U1.23 (PA13)
/UART_RX: TP2.1, U1.20 (PA10)
/UART_TX: TP1.1, U1.19 (PA9)
/VBUS_SENSE: R5.2, R6.1, U1.13 (PA7)
/VMID: C12.1, R12.2, R13.2, R14.1, R15.1
/VMID_EN: R13.1, U1.8 (PA2)
/VSW_SENSE: C5.1, R7.2, R8.1, U1.15 (PB1)
/V_MID1: R10.2, R11.1
GND: C1.2, C2.2, C3.2, C4.2, C5.2, C6.2, C7.2, C8.2, C9.2, C10.2, C11.2, C12.2, C13.2, C14.2, D2.1 (K), D3.1 (K), J1.A1 (GND), J1.A12 (GND), J1.B1 (GND), J1.B12 (GND), J1.SH (SHIELD), J2.1, J3.1, J4.5, J5.2, Q2.2 (S), R1.2, R2.2, R3.2, R6.2, R8.2, R9.2, R14.2, R23.2, R30.2, SW1.2, SW2.2, SW3.2, SW4.2, TP5.1, U1.16 (VSS), U1.32 (VSS), U2.2 (V_{SS}), U3.1 (GND), U4.3 (A)
unnamed: BZ1.1 (+), R27.2
unnamed: BZ1.2 (-), R28.2
unnamed: D1.2 (A), R4.2
unnamed: D4.4 (BK), R26.2
unnamed: D4.3 (GK), R25.2
unnamed: D4.2 (RK), R24.2
unnamed: R3.1, U2.5 (PROG)
unnamed: R29.2, R30.1, U4.2 (REF)
VBUS: C1.1, J1.A4 (VBUS), J1.A9 (VBUS), J1.B4 (VBUS), J1.B9 (VBUS), R4.1, R5.1, U2.4 (V_{DD})

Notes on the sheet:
ADC_V = VMID + (VIN - VMID) x R12 / (R10 + R11 + R12) VIN = ADC_V + (ADC_V - VMID) x 20.0; VMID is measured on ADC_VMID. VMID_EN high only while measuring: VMID = 1.56 V, range -31 to +32 V. Overload current is set by R10 + R11 (3 uA at 30 V) into the PA4 clamp.
C6, C7 at VDD pins 1 and 17; C8, C9 at VDDA pin 5
J4 unpopulated: hold a header in it or solder one for an ST-Link. 1 3V0 2 SWDIO 3 SWCLK 4 NRST 5 GND
Power: USB-C charging, LiPo, 3.0 V rail
Voltage input: 10 Mohm, +/-30 V
R3 = 10k: 100 mA charge (1000 V / R3). Size it for 0.5-1 C of the cell.
Buttons use the MCU pull-ups and wake it from Stop mode.
Display, LED, piezo, buttons
Resistance / continuity / diode input, protected to +/-30 V
SSD1306 module, pins GND VCC SCL SDA. Its own pull-ups hold SDA/SCL; Q1 cuts its supply when the meter is off.
Rev 3. Not for mains: inputs are rated 30 V DC max. The 3.0 V rail stays on (1 uA LDO, MCU in Stop); SW5 disconnects the battery for storage.
Low range (0-100k, continuity, diode): drive OHM_LO high, RX = R17 x ADC_OHM / (ADC_ELO - ADC_OHM). High range (100k-10M): drive OHM_HI high, RX = R20 x ADC_OHM / (VDD - ADC_OHM). The unused drive pin stays analog (high-Z). Firmware first pulls OHM_LO low: a passive load then reads ~0 V, a source d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
SW5 disconnects the battery; charging still works.
1 COM 2 V 3 OHM / continuity / diode
U4 clamps +3V0 at 3.3 V (2.495 V x (1 + R29 / R30))
MCU

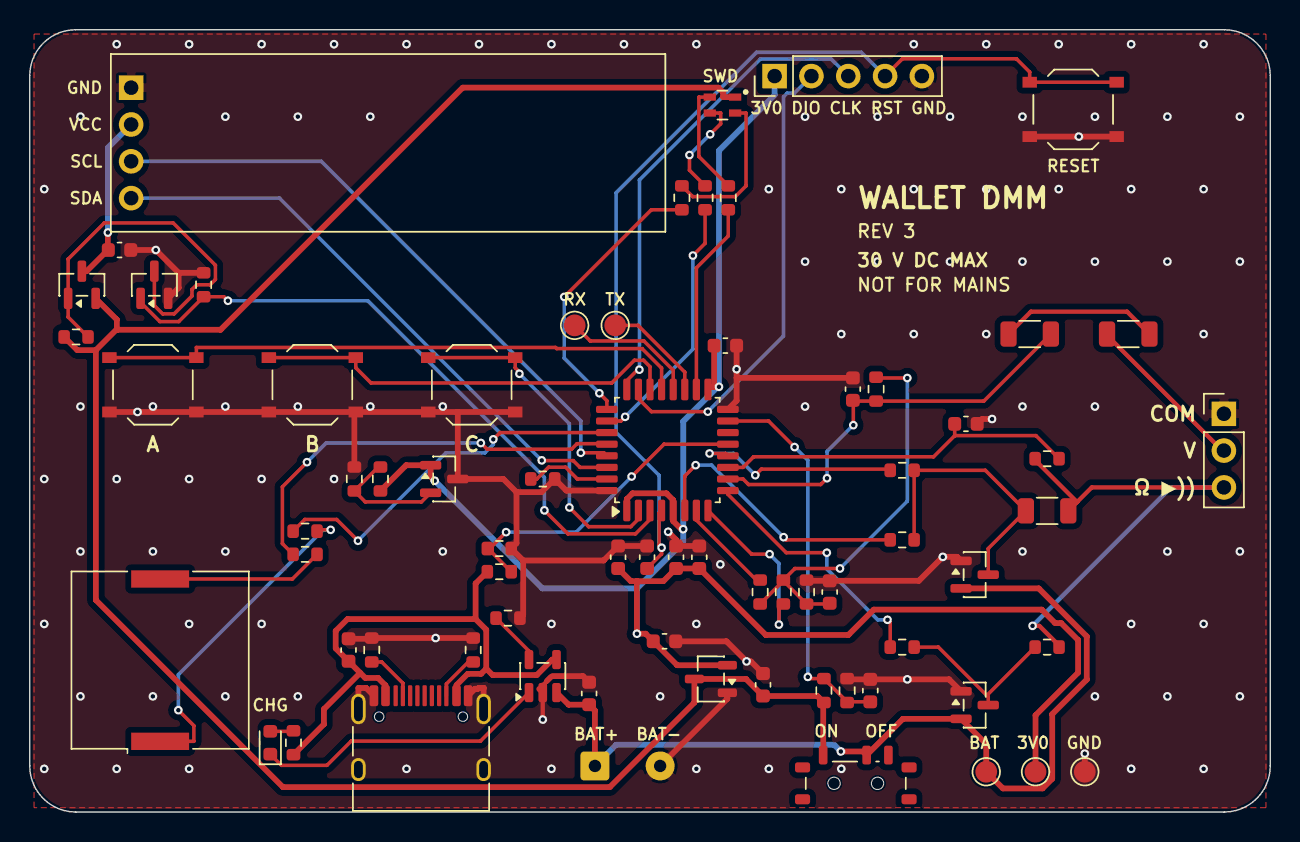
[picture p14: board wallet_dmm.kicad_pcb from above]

Board: 2 copper layers, 85.6 x 54.0 mm, 70 parts (0 on the bottom side), 50 nets.

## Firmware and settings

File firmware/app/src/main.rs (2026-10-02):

//! Wallet DMM firmware for the STM32L051K8.
//!
//! Measures on a timer, draws on the OLED, and reads the buttons in their own
//! tasks. All maths and screen layout live in `dmm-core`; this file owns the
//! pins. A one-line log of every reading goes out on USART1 (TP1, 115200 8N1),
//! and USART1 RX (TP2) takes one command: `cal <volts>` with a known voltage
//! on the V input sets the voltage gain.
#![no_std]
#![no_main]

mod adc;
mod eeprom;
mod power;

use core::ptr::{read_volatile, write_volatile};

use dmm_core::format::{self, Text};
use dmm_core::frontend::{self, Calibration, Range, Value};
use dmm_core::render;
use dmm_core::ui::{Action, Button, Measurement, Mode, Press, Ui};
use embassy_executor::Spawner;
use embassy_futures::select::{select, select3, Either, Either3};
use embassy_stm32::exti::{self, ExtiInput};
use embassy_stm32::gpio::{Flex, Input, Level, Output, OutputType, Pull, Speed};
use embassy_stm32::i2c::{self, I2c};
use embassy_stm32::interrupt::InterruptExt;
use embassy_stm32::mode::Async;
use embassy_stm32::rcc::Sysclk;
use embassy_stm32::time::Hertz;
use embassy_stm32::timer::low_level::CountingMode;
use embassy_stm32::timer::low_level::OutputPolarity;
use embassy_stm32::timer::simple_pwm::{PwmPin, SimplePwm};
use embassy_stm32::usart::{self, Uart, UartTx};
use embassy_stm32::{bind_interrupts, interrupt, peripherals};
use embassy_sync::blocking_mutex::raw::CriticalSectionRawMutex;
use embassy_sync::channel::Channel;
use embassy_time::{Instant, Timer};
use panic_halt as _;
use ssd1306::{prelude::*, I2CDisplayInterface, Ssd1306};

use adc::Adc;

bind_interrupts!(struct Irqs {
    EXTI4_15 => exti::InterruptHandler<interrupt::typelevel::EXTI4_15>;
});

static PRESSES: Channel<CriticalSectionRawMutex, (Button, Press), 4> = Channel::new();
static COMMANDS: Channel<CriticalSectionRawMutex, Command, 2> = Channel::new();
static RX_BYTES: Channel<CriticalSectionRawMutex, u8, 32> = Channel::new();

enum Command {
    /// The V input is at this many µV: set the gain to match.
    Cal(i64),
    Unknown,
}

/// Debounces one button and tells short presses from long ones.
#[embassy_executor::task(pool_size = 3)]
async fn button(mut pin: ExtiInput<'static, Async>, which: Button, long_ms: u64) {
    loop {
        pin.wait_for_falling_edge().await;
        Timer::after_millis(20).await;
        if pin.is_high() {
            continue;
        }
        let press = match select(pin.wait_for_high(), Timer::after_millis(long_ms)).await {
            Either::First(()) => Press::Short,
            Either::Second(()) => Press::Long,
        };
        PRESSES.send((which, press)).await;
        pin.wait_for_high().await;
        Timer::after_millis(20).await;
    }
}

const USART1_CR1: usize = 0x4001_3800;
const USART1_ISR: usize = 0x4001_381C;
const USART1_ICR: usize = 0x4001_3820;
const USART1_RDR: usize = 0x4001_3824;
const CR1_RXNEIE: u32 = 1 << 5;
const ISR_RXNE: u32 = 1 << 5;

/// Passes received bytes on to `commands`. Transmit stays blocking, so the
/// log never waits on an interrupt.
#[interrupt]
fn USART1() {
    unsafe {
        if read_volatile(USART1_ISR as *const u32) & ISR_RXNE != 0 {
            let _ = RX_BYTES.try_send(read_volatile(USART1_RDR as *const u32) as u8);
        }
        // Clear framing, noise and overrun errors so reception carries on.
        write_volatile(USART1_ICR as *mut u32, 0b1110);
    }
}

/// Reads command lines from USART1 RX.
#[embassy_executor::task]
async fn commands() {
    let mut line = Text::<24>::new();
    loop {
        match RX_BYTES.receive().await {
            b'\r' | b'\n' => {
                let text = line.as_str().trim();
                if !text.is_empty() {
                    let command = match text.strip_prefix("cal ").and_then(|v| format::parse_uv(v.trim())) {
                        Some(uv) => Command::Cal(uv),
                        None => Command::Unknown,
                    };
                    COMMANDS.send(command).await;
                }
                line = Text::new();
            }
            c => line.push(c),
        }
    }
}

/// The pins that set up the two inputs.
struct FrontEnd {
    vmid_en: Output<'static>,
    ohm_lo: Flex<'static>,
    ohm_hi: Flex<'static>,
}

impl FrontEnd {
    /// Pull the Ω input low through R16 + R17 to see whether a source is
    /// connected to it: a passive load reads ~0 V then.
    fn sink(&mut self) {
        self.ohm_hi.set_as_analog();
        self.ohm_lo.set_low();
        self.ohm_lo.set_as_output(Speed::Low);
    }

    /// Bias the V divider or drive one ohms reference; the other drive pin
    /// stays analog (high impedance). Returns how long the nodes need to settle.
    fn set(&mut self, mode: Mode, range: Range) -> u64 {
        let (vmid, drive) = match mode {
            Mode::Volts => (true, None),
            Mode::Ohms => (false, Some(range)),
            Mode::Continuity | Mode::Diode => (false, Some(Range::Low)),
            Mode::Info => (false, None),
        };
        self.vmid_en.set_level(if vmid { Level::High } else { Level::Low });
        for (pin, r) in [(&mut self.ohm_lo, Range::Low), (&mut self.ohm_hi, Range::High)] {
            if drive == Some(r) {
                pin.set_high();
                pin.set_as_output(Speed::Low);
            } else {
                pin.set_as_analog();
            }
        }
        match (mode, drive) {
            (Mode::Volts, _) => 150,       // 5 x (448 kΩ x 47 nF)
            (_, Some(Range::High)) => 150, // 5 x (1.05 MΩ x 22 nF)
            (_, Some(Range::Low)) => 10,   // 5 x (57 kΩ x 22 nF)
            _ => 0,
        }
    }

    fn off(&mut self) {
        self.vmid_en.set_low();
        self.ohm_lo.set_as_analog();
        self.ohm_hi.set_as_analog();
    }
}

/// Active-low LED outputs.
struct Leds {
    red: Output<'static>,
    green: Output<'static>,
    blue: Output<'static>,
}

impl Leds {
    fn set(&mut self, red: bool, green: bool, blue: bool) {
        for (led, on) in [(&mut self.red, red), (&mut self.green, green), (&mut self.blue, blue)] {
            led.set_level(if on { Level::Low } else { Level::High });
        }
    }
}

struct Log(UartTx<'static, embassy_stm32::mode::Blocking>);

impl Log {
    fn line(&mut self, parts: &[&str]) {
        for p in parts {
            let _ = self.0.blocking_write(p.as_bytes());
        }
        let _ = self.0.blocking_write(b"\r\n");
    }
}

fn number(v: i64) -> Text<21> {
    let mut t = Text::new();
    if v < 0 {
        t.push(b'-');
    }
    t.push_uint(v.unsigned_abs(), 1);
    t
}

#[embassy_executor::main]
async fn main(spawner: Spawner) {
    let mut config = embassy_stm32::Config::default();
    config.rcc.hsi = true;
    config.rcc.sys = Sysclk::HSI;
    let p = embassy_stm32::init(config);

    let mut uart_config = usart::Config::default();
    uart_config.baudrate = 115_200;
    // `_rx` lives as long as main: dropping it would turn the receiver off.
    let (tx, _rx) = Uart::new_blocking(p.USART1, p.PA10, p.PA9, uart_config).unwrap().split();
    let mut log = Log(tx);
    log.line(&["wallet-dmm rev 3"]);
    unsafe {
        write_volatile(USART1_CR1 as *mut u32, read_volatile(USART1_CR1 as *const u32) | CR1_RXNEIE);
        interrupt::USART1.unpend();
        interrupt::USART1.enable();
    }
    spawner.spawn(commands().unwrap());

    let mut fe = FrontEnd {
        vmid_en: Output::new(p.PA2, Level::Low, Speed::Low),
        ohm_lo: Flex::new(p.PA6),
        ohm_hi: Flex::new(p.PA3),
    };
    fe.off();
    let vbus = Input::new(p.PA7, Pull::None);
    let mut leds = Leds {
        red: Output::new(p.PA15, Level::High, Speed::Low),
        green: Output::new(p.PB3, Level::High, Speed::Low),
        blue: Output::new(p.PA8, Level::High, Speed::Low),
    };

    // Piezo: TIM22 CH1 and CH2 in antiphase at 4 kHz, 6 Vp-p across it.
    let mut piezo = SimplePwm::new(
        p.TIM22,
        Some(PwmPin::new(p.PB4, OutputType::PushPull)),
        Some(PwmPin::new(p.PB5, OutputType::PushPull)),
        None,
        None,
        Hertz(4_000),
        CountingMode::EdgeAlignedUp,
    );
    piezo.ch1().set_duty_cycle_percent(50);
    piezo.ch2().set_duty_cycle_percent(50);
    piezo.ch2().set_polarity(OutputPolarity::ActiveLow);

    // OLED module: power it through Q1, then give its regulator time to start.
    let mut oled_en = Output::new(p.PC15, Level::High, Speed::Low);
    Timer::after_millis(50).await;
    let mut i2c_config = i2c::Config::default();
    i2c_config.frequency = Hertz(400_000);
    let i2c = I2c::new_blocking(p.I2C1, p.PB6, p.PB7, i2c_config);
    let mut display = Ssd1306::new(I2CDisplayInterface::new(i2c), DisplaySize128x32, DisplayRotation::Rotate0)
        .into_buffered_graphics_mode();
    let display_ok = display.init().is_ok();
    if !display_ok {
        log.line(&["oled: no answer"]);
    }

    let mut adc = Adc::new();
    let factory = eeprom::factory();
    let mut cal = eeprom::load().unwrap_or_default();

    let buttons = [
        (ExtiInput::new(p.PA11, p.EXTI11, Pull::Up, Irqs), Button::A, 1500),
        (ExtiInput::new(p.PA12, p.EXTI12, Pull::Up, Irqs), Button::B, 1500),
        (ExtiInput::new(p.PC14, p.EXTI14, Pull::Up, Irqs), Button::C, 3000),
    ];
    for (pin, which, long_ms) in buttons {
        spawner.spawn(button(pin, which, long_ms).unwrap());
    }

    let mut ui = Ui::new();
    let mut range = Range::Low;
    let mut settle = fe.set(ui.mode, range);
    let mut last = Instant::now();
    let mut blink = false;

    loop {
        let period = ui.mode.period_ms(range) as u64;
        let wait = Timer::after_millis(period.max(settle));
        match select3(PRESSES.receive(), COMMANDS.receive(), wait).await {
            Either3::First((which, press)) => {
                let name = match which {
                    Button::A => "A",
                    Button::B => "B",
                    Button::C => "C",
                };
                log.line(&["button ", name, if press == Press::Long { " long" } else { "" }]);
                let before = ui.mode;
                match ui.press(which, press) {
                    Action::PowerOff => {
                        let _ = display.set_display_on(false);
                        power_off(&mut log, &mut fe, &mut leds, &mut adc, &mut piezo, &mut oled_en)
                    }
                    Action::StoreZero(mode, raw) => {
                        cal = zeroed(cal, mode, raw);
                        eeprom::store(&cal);
                        log.line(&["zero stored"]);
                    }
                    Action::None => {}
                }
                if ui.mode != before {
                    range = Range::Low;
                    settle = fe.set(ui.mode, range);
                }
                continue;
            }
            Either3::Second(Command::Cal(true_uv)) => {
                if ui.mode != Mode::Volts {
                    log.line(&["cal: switch to DC V first"]);
                    continue;
                }
                let vdda = frontend::vdda_uv(&factory, adc.average(adc::CH_VREFINT, 4));
                let tap = adc.average(adc::CH_V_TAP, 64);
                let mid = adc.average(adc::CH_VMID, 16);
                let Value::Ok(reading) = frontend::volts(&cal, vdda, tap, mid) else {
                    log.line(&["cal: overload"]);
                    continue;
                };
                match frontend::gain_ppm(&cal, reading, true_uv) {
                    Some(gain) => {
                        cal.volts_gain_ppm = gain;
                        eeprom::store(&cal);
                        log.line(&["gain stored ", number(gain as i64).as_str(), " ppm"]);
                    }
                    None => log.line(&["cal: reading ", number(reading).as_str(), " uV is too far off"]),
                }
                continue;
            }
            Either3::Second(Command::Unknown) => {
                log.line(&["commands: cal <volts on the V input>"]);
                continue;
            }
            Either3::Third(()) => settle = 0,
        }

        // One round of measurements.
        let vref = adc.average(adc::CH_VREFINT, 2);
        let vdda = frontend::vdda_uv(&factory, vref);
        let value = match ui.mode {
            Mode::Volts => {
                let tap = adc.average(adc::CH_V_TAP, 8);
                let mid = adc.average(adc::CH_VMID, 2);
                frontend::volts(&cal, vdda, tap, mid)
            }
            Mode::Ohms | Mode::Continuity | Mode::Diode => {
                let r = if ui.mode == Mode::Ohms { range } else { Range::Low };
                // First look for a source on the input with the drive pulled low
                // (5 x 1.3 ms for C13 to follow), then measure.
                fe.sink();
                Timer::after_millis(7).await;
                let live = frontend::input_is_live(frontend::to_uv(adc.average(adc::CH_OHM, 1), vdda));
                if live {
                    Value::Overload
                } else {
                    Timer::after_millis(fe.set(ui.mode, r)).await;
                    let input = frontend::to_uv(adc.average(adc::CH_OHM, 4), vdda);
                    let drive = match r {
                        Range::Low => frontend::to_uv(adc.average(adc::CH_E_LO, 2), vdda),
                        Range::High => vdda,
                    };
                    if ui.mode == Mode::Diode {
                        frontend::diode(vdda, drive, input)
                    } else {
                        frontend::ohms(&cal, r, vdda, drive, input)
                    }
                }
            }
            Mode::Info => Value::Open,
        };
        let battery_uv = frontend::battery_uv(vdda, adc.average(adc::CH_BATTERY, 1));
        let m = Measurement {
            value,
            range,
            battery_uv,
            battery_pct: frontend::battery_percent(battery_uv),
            usb: vbus.is_high(),
            temperature_dc: frontend::temperature_dc(&factory, vdda, adc.average(adc::CH_TEMPERATURE, 1)),
            vdda_uv: vdda,
        };

        // A voltage on the ohms input: stop driving it until the next check.
        if value == Value::Overload && ui.mode != Mode::Volts {
            fe.off();
        } else if ui.mode == Mode::Ohms {
            let next = frontend::next_range(range, value);
            if next != range {
                range = next;
                settle = fe.set(ui.mode, range);
            }
        }

        let now = Instant::now();
        let elapsed = (now - last).as_millis() as u32;
        last = now;
        if ui.tick(elapsed, &m) == Action::PowerOff {
            let _ = display.set_display_on(false);
            power_off(&mut log, &mut fe, &mut leds, &mut adc, &mut piezo, &mut oled_en);
        }

        let screen = ui.screen(&m);
        if display_ok {
            let _ = render::draw(&screen, &mut display);
            let _ = display.flush();
        }
        let beep = ui.beep(&m);
        if beep {
            piezo.ch1().enable();
            piezo.ch2().enable();
        } else {
            piezo.ch1().disable();
            piezo.ch2().disable();
        }
        blink = !blink;
        leds.set(value == Value::Overload && ui.mode != Mode::Volts, beep, m.usb && blink);

        let raw = match value {
            _ if ui.mode == Mode::Info => Text::from("-"),
            Value::Ok(v) => number(v),
            Value::Open => Text::from("open"),
            Value::Overload => Text::from("overload"),
        };
        log.line(&[
            ui.mode.title(),
            " ",
            raw.as_str(),
            " vdda ",
            number(vdda as i64).as_str(),
            " bat ",
            number(battery_uv as i64).as_str(),
            " temp ",
            number(m.temperature_dc as i64).as_str(),
        ]);
    }
}

/// Folds a reading taken with the probes shorted into the calibration.
fn zeroed(mut cal: Calibration, mode: Mode, raw: i64) -> Calibration {
    match mode {
        Mode::Volts => cal.volts_offset_uv += raw as i32,
        _ => cal.lead_mohm = (cal.lead_mohm as i64 + raw).max(0) as u32,
    }
    cal
}

fn power_off(
    log: &mut Log,
    fe: &mut FrontEnd,
    leds: &mut Leds,
    adc: &mut Adc,
    piezo: &mut SimplePwm<'static, peripherals::TIM22>,
    oled_en: &mut Output<'static>,
) -> ! {
    log.line(&["off"]);
    let _ = log.0.blocking_flush();
    fe.off();
    leds.set(false, false, false);
    piezo.ch1().disable();
    piezo.ch2().disable();
    adc.off();
    // Cut the module's supply, and stop the I2C pins feeding it through its pull-ups.
    oled_en.set_low();
    power::i2c_pins_analog();
    power::stop_until_button()
}

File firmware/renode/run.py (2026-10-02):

#!/usr/bin/env python3
"""Runs the real firmware binary in Renode and shows what the OLED would.

The ELF from app/ runs on an STM32L051 model (stm32l051.repl). adc_l0.py
stands in for the ADC and the analog front end; the SSD1306 is a stub that
reports every I2C write. A scripted session presses buttons and changes what
the probes touch, and this script turns the captured I2C traffic back into
frames (out/frames/*.png, and out/session.gif) next to the UART log.

    cargo build --release --manifest-path ../app/Cargo.toml
    python3 run.py
"""

import shutil
import subprocess
import sys
from pathlib import Path

HERE = Path(__file__).resolve().parent
OUT = HERE / "out"
ELF = HERE.parent / "app" / "target" / "thumbv6m-none-eabi" / "release" / "wallet-dmm"
sys.path.insert(0, str(HERE.parent / "sim"))

# Buttons: (port, pin). They are active low with pull-ups.
BUTTONS = {"A": ("gpioPortA", 11), "B": ("gpioPortA", 12), "C": ("gpioPortC", 14)}

# (name, probes, button presses before running, seconds to run)
# Probes: vin = volts on V; rx = ohms on OHM (or "open"); vext = volts on OHM;
# vf = a diode's forward voltage on OHM; usb = 1 when on USB.
# A press of ("uart", text) types text into USART1 RX instead.
STEPS = [
    ("volts_5V", {"vin": 5.0}, [], 1.5),
    ("volts_12V34", {"vin": 12.34}, [], 0.6),
    ("volts_neg3V3", {"vin": -3.3}, [], 0.6),
    ("volts_hold", {"vin": -3.3}, [("B", 0.1)], 0.4),
    ("volts_hold_kept", {"vin": 20.0}, [], 0.6),
    ("volts_overload", {"vin": 45.0}, [("B", 0.1)], 0.6),
    ("volts_10V", {"vin": 10.0}, [], 0.8),
    # Another meter says the input is at 10.050 V: set the gain to match.
    ("volts_cal_10V05", {"vin": 10.0}, [("uart", "cal 10.05\r")], 2.0),
    ("ohms_4k7", {"rx": 4700}, [("A", 0.1)], 0.8),
    ("ohms_470k", {"rx": 470e3}, [], 1.2),
    ("ohms_open", {"rx": "open"}, [], 1.0),
    ("ohms_voltage", {"vext": 12.0}, [], 0.6),
    ("ohms_negative_voltage", {"vext": -5.0}, [], 0.6),
    ("continuity_short", {"rx": 0.3}, [("A", 0.1)], 0.5),
    ("continuity_open", {"rx": "open"}, [], 0.4),
    ("diode_1n4148", {"vf": 0.517}, [("A", 0.1)], 0.6),
    ("info_usb", {"usb": 1}, [("A", 0.1)], 2.2),
    ("power_off", {}, [("A", 1.8)], 0.5),
    ("wake_volts_0V", {"vin": 0.0}, [("B", 0.1)], 1.5),
    ("zero_stored", {"vin": 0.0}, [("C", 3.3)], 0.8),
    ("power_off_again", {}, [("A", 1.8)], 0.5),
    ("wake_calibration_kept", {"vin": 10.0}, [("B", 0.1)], 2.0),
]

HOOKS = r'''
from Antmicro.Renode.Core import EmulationManager
m = list(EmulationManager.Instance.CurrentEmulation.Machines)[0]
trace = open(TRACE, 'w')
def now():
    return m.ElapsedVirtualTime.TimeElapsed.TotalSeconds
def on_i2c(data):
    trace.write('%.6f I2C %s\n' % (now(), ' '.join('%02x' % (b & 0xff) for b in data)))
def on_uart(c):
    trace.write('%.6f UART %02x\n' % (now(), c & 0xff))
def probes(text):
    # Closed at once: IronPython has no refcounting, so an unclosed file is
    # flushed whenever the GC gets to it, and the ADC could read it empty.
    with open(SCENARIO, 'w') as f:
        f.write(text.replace(';', '\n'))
def mark(name):
    b = m.SystemBus
    trace.write('%.6f MARK %s %08x %08x %08x %08x\n' % (now(), name, b.ReadDoubleWord(0x50000014),
                b.ReadDoubleWord(0x50000414), b.ReadDoubleWord(0x50000814), b.ReadDoubleWord(0x40011420)))
    trace.flush()
m['sysbus.i2c1.oled'].DataReceived += on_i2c
m['sysbus.usart1'].CharReceived += on_uart
'''


def seconds(t):
    return f'"00:00:{t:09.6f}"'


def script():
    OUT.mkdir(exist_ok=True)
    scenario = OUT / "scenario.txt"
    trace = OUT / "trace.txt"
    adc = (HERE / "adc_l0.py").read_text().replace("SCENARIO_PATH", repr(str(scenario)))
    (OUT / "adc_l0.py").write_text(adc)
    repl = (HERE / "stm32l051.repl").read_text().replace('"ADC_PY"', f'"{OUT / "adc_l0.py"}"')
    (OUT / "stm32l051.repl").write_text(repl)
    (OUT / "hooks.py").write_text(f"TRACE = {str(trace)!r}\nSCENARIO = {str(scenario)!r}\n" + HOOKS)
    scenario.write_text("vin=0\n")
    lines = [
        'mach create "dmm"',
        f"machine LoadPlatformDescription @{OUT / 'stm32l051.repl'}",
        # A system reset (the firmware resets itself when it wakes) reloads the
        # image. It also clears two things the real chip keeps: the buttons'
        # pull-ups (the model's inputs go low), and EXTI_IMR's reset value,
        # which unmasks the direct lines such as USART1's interrupt.
        "macro reset",
        '"""',
        f"    sysbus LoadELF @{ELF}",
        "    sysbus WriteDoubleWord 0x40010400 0x3F840000",
        *[f"    sysbus.{port} OnGPIO {pin} true" for port, pin in BUTTONS.values()],
        '"""',
        "runMacro $reset",
        "logLevel 3",
    ]
    lines += ["sysbus.gpioPortA OnGPIO 7 false", f"python \"execfile('{OUT / 'hooks.py'}')\""]
    for name, probes, presses, run_for in STEPS:
        text = ";".join(f"{k}={v}" for k, v in probes.items() if k != "usb")
        lines.append(f'python "probes(\'{text}\')"')
        lines.append(f"sysbus.gpioPortA OnGPIO 7 {'true' if probes.get('usb') else 'false'}")
        for button, held in presses:
            if button == "uart":
                lines += [f"sysbus.usart1 WriteChar {b}" for b in held.encode()]
                continue
            port, pin = BUTTONS[button]
            # Renode 1.16 updates PC14's input but does not pass it on to the
            # EXTI, so button C also drives its EXTI line directly.
            extra = port == "gpioPortC"
            lines += [f"sysbus.{port} OnGPIO {pin} false"] + ([f"sysbus.exti OnGPIO {pin} false"] if extra else [])
            lines += [f"emulation RunFor {seconds(held)}", f"sysbus.{port} OnGPIO {pin} true"]
            lines += [f"sysbus.exti OnGPIO {pin} true"] if extra else []
        lines += [f"emulation RunFor {seconds(run_for)}", f'python "mark(\'{name}\')"']
    lines.append("quit")
    path = OUT / "session.resc"
    path.write_text("\n".join(lines) + "\n")
    return path, trace
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

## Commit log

2024-07-21 added schematic and pcb files
    [wallet-dmm.kicad_pcb, wallet-dmm.kicad_sch]
2024-07-21 directory structure change
    [wallet-dmm.kicad_pcb, wallet-dmm.kicad_sch]
2024-07-21 Revert "directory structure change"
    This reverts commit aa9815be2f0c9639624ed1b2c933063fcc6c1c88.
    [wallet-dmm.kicad_pcb, wallet-dmm.kicad_sch]
2024-07-21 file name changes
    [wallet-dmm.kicad_pcb, wallet-dmm.kicad_sch, wallet_dmm.kicad_pcb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]
2024-07-28 Fixed runner-dependent environment bug.
    The runner that executes the kicad-cli commands needs to be the same runner that installed KiCAD.
2024-07-28 Removed PCB diff export.
    Doesn't work yet and we don't even have a PCB so we'll just diff schematics for now.
2024-07-29 Added docs folder and BOM csv.
    [wallet_dmm_bom.csv]
2024-07-29 Created kicad_diff directory for storing kicad_diff images.
2024-07-29 Moved svg diffs to docs/kicad_diffs
2024-07-29 Made placeholder diff to create kicad_diff directory
2024-07-29 Added microcontroller to BOM
    [wallet_dmm_bom.csv]
2024-07-30 Added oscillator (TLC555CDR) to BOM csv
    [wallet_dmm_bom.csv]
2024-07-30 Added piezo driver oscillator (based on TLC555CDR) to schematic. Needs component values calculated for oscillator parameters (frequency, etc).
    [wallet_dmm.kicad_sch]
2024-08-31 Added temperature sensor to schematic and added .gitignore file.
    [wallet_dmm.kicad_sch]
2024-10-11 Added OLED footprint
    [wallet_dmm.kicad_sch]
2024-10-11 Added piezo buzzer and control circuitry.
    [wallet_dmm.kicad_sch]
2024-10-13 Merged with working branch. PCB completed and introduced PCB diff functionality in create_diff.yml.
    [wallet_dmm.kicad_pcb, wallet_dmm.kicad_sch]
2024-10-13 Update silkscreen reference placements.
    [wallet_dmm.kicad_pcb]
2024-10-13 Added silkscreen signature and revision number.
    [wallet_dmm.kicad_pcb]
2024-10-13 Updated BOM.
    [wallet_dmm_bom.csv]
2024-10-13 Final commit before sending off to JLC.
    [wallet_dmm.kicad_pcb]
2026-09-30 Revision 3.
    LiPo with USB-C charging and a 3.0 V rail replaces the CR1025. The MCU
    drives the piezo directly, so the 555 and both MOSFETs are gone. SWD is
    on PA13/PA14 with NRST. Separate V and ohm inputs, each protected to
    30 V. LED resistors, decoupling at the pins, 0.8 mm board, JLCPCB parts.
    The schematic and board are now generated by scripts/ and checked by
    ERC and DRC; fab/ holds the files for ordering.
    [bom-jlcpcb.csv, bom.csv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]
2026-10-02 Firmware, simulation and 3D models for rev 3.
    Rust/Embassy firmware for the STM32L051, with the measurement maths and UI
    in a host-tested crate. The front end is simulated in ngspice and the
    release binary runs in Renode. The simulation found that a fault on the
    inputs could pull the 3.0 V rail up while the MCU sleeps, so U4 (TL431)
    now clamps it; R13/R14 and C13 changed as well. Every part has a 3D model,
    with renders in docs/.
    [bom-jlcpcb.csv, bom.csv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]
